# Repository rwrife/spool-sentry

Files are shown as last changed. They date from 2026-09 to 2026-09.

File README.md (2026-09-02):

# Spool Sentry

> USB-powered ESP32-C3 monitor for 3D-printing hobbyists to track dry-box humidity, temperature, and filament spool mass through a private local dashboard without controlling heaters or printers.

## Overview

Spool Sentry is a small, repairable monitor for a passive filament dry box. A load cell under one spool records mass trends while a digital temperature/humidity sensor records the box environment. An ESP32-C3-class controller keeps bounded local history and serves a phone/desktop-friendly web interface on the local network. USB CDC remains the setup and recovery path.

The goal is practical awareness: see whether a box is staying dry, record desiccant changes, and estimate remaining filament after the user enters empty-spool mass. It is **not** a dryer controller, printer integration, certified hygrometer, or safety device.

## Motivation

Opaque boxes hide both environmental drift and dwindling material. Stick-on hygrometers show only the present, and manually weighing a spool interrupts storage. Spool Sentry combines two explainable observations without requiring a vendor account, subscription, or internet service.

## Target users

- Home 3D-printing hobbyists who store moisture-sensitive filament
- Small workshops that want a local history for one frequently used spool
- Makers who prefer editable hardware, replaceable sensors, and portable data

## Concrete use cases

- Check current box humidity and temperature from a phone on the same LAN.
- View hourly trends and annotate a desiccant recharge or spool swap.
- Tare/calibrate the scale, enter an empty-spool mass, and see gross/net mass with an uncertainty indicator.
- Export measurements and events as CSV/JSON before clearing local history.
- Recover configuration over USB if Wi-Fi credentials change.

## Intended workflow

1. Assemble the low-voltage carrier, sensor lead, load-cell platform, and enclosure using the bring-up guide that the backlog will create.
2. Power it from a suitable USB 5 V supply; no battery or mains wiring is part of the project.
3. Hold the physical setup button to open a short-lived onboarding session, then configure local Wi-Fi from the device-hosted page or USB CDC.
4. Calibrate with a documented reference mass, enter the spool's empty mass, and place the spool on the platform.
5. Review live values and local trends, add spool/desiccant events, and export or delete data at any time.

## MVP features

- One replaceable load-cell/ADC channel and one digital humidity/temperature channel
- Explicit sensor freshness, calibration state, and invalid/out-of-range statuses
- Gross mass, user-derived net filament estimate, and visible uncertainty—not false precision
- Bounded flash history with retention controls and event annotations
- Responsive local web UI with keyboard, screen-reader, reduced-motion, high-contrast, and non-color-only states
- Versioned CSV/JSON export and JSON backup/restore
- USB CDC provisioning, diagnostics, firmware recovery, and Wi-Fi-free snapshot access
- Physical setup/tare button and status indicator

## Non-goals

- Heater, fan, mains, battery-charging, relay, or printer control
- Fire, smoke, flood, food, medical, or life-safety monitoring
- Certified environmental measurement or guaranteed filament condition/print quality
- Automatic material-type diagnosis, purchasing, cloud accounts, remote internet access, or multi-site fleet management
- Multi-spool inventory, RFID, camera, or slicing software integration in the MVP

## Privacy, permissions, and data storage

Spool Sentry has no cloud backend, telemetry, advertising, or required account. Measurements, calibration data, annotations, and network configuration remain on the device; exports are created only when requested. The local web app requests no phone contacts, location, camera, microphone, Bluetooth, or notification permission. Wi-Fi access is limited to local setup and local device use. USB works without network access.

The baseline LAN protocol is not a promise of hostile-network security: deployment assumes a trusted home/workshop LAN, uses proof-of-presence onboarding, rejects cross-origin mutation, and keeps remote access disabled. Documentation will explain credential reset, export redaction, retention, deletion, and the limitations of unencrypted local HTTP if that remains the chosen transport.

## Safety limits

- SELV USB 5 V input only; use a suitable enclosed/certified USB supply.
- No connection to printer power, heaters, mains, batteries, or safety interlocks.
- Keep electronics away from hot zones, moving printer parts, liquids, and loose filament paths.
- Load readings are informational. Do not use the platform to support people, hazardous loads, or critical processes.
- Humidity/temperature readings and remaining-filament estimates can drift or fail. The device must surface stale/invalid data rather than imply safety or guaranteed print success.

## Hardware and source-of-truth plan

The planned editable KiCad project is:

- `hardware/spool-sentry.kicad_pro`
- `hardware/spool-sentry.kicad_sch`
- `hardware/spool-sentry.kicad_pcb`

These files **do not exist yet**; this repository is currently a documentation/backlog scaffold. The backlog requires real editable KiCad sources, ERC/DRC evidence, firmware/app builds, bring-up measurements, and fabrication outputs before any hardware-complete claim.

Final BOM data belongs in KiCad schematic symbol properties (`Manufacturer`, `MPN`, supplier fields, and notes) and is exported to tracked `bom/bom.csv`. `bom/preliminary-bom.csv` is planning-only and contains no validated sourcing or prices.

## Current status and milestones

**Status: requirements/architecture baseline plus toolchain proof.** The v0.1 requirements, editable architecture diagrams, protocol schema/fixture, risk register, and verification matrix are frozen. A pinned Rust host-test and ESP32-C3 target-link proof exists, but there is still no schematic, PCB, functional firmware/app, calibrated instrument, fabricated board, assembly, ERC/DRC result, flash/boot evidence, or bench/field test.

1. Freeze measurable requirements and risk boundaries.
2. Select exact components from manufacturer datasheets and create the KiCad schematic/BOM.
3. Lay out and verify the carrier PCB.
4. Build firmware and the local web companion against simulated interfaces.
5. Assemble, calibrate, integrate, and publish honest fabrication/release evidence.

See [PLAN.md](PLAN.md), the canonical [v0.1 requirements](docs/requirements.md), [architecture](docs/architecture.md), [risk register](docs/risk-register.md), [verification matrix](docs/verification-matrix.md), and the GitHub issue backlog.

## Development quickstart

The currently implemented checks require Python 3 plus rustup. The proof pins and installs its exact Rust version, components, and ESP32-C3 target:

```sh
./scripts/verify.sh
```

This checks requirement traceability, local Markdown links, the protocol schema/fixture, Rust formatting/clippy/host tests, and an ESP32-C3 release link. See [the toolchain decision](docs/toolchain.md) for exact evidence limits. KiCad 9+, the companion Node/pnpm workspace, selected-part drivers, flashing, and bench procedures arrive in later issues and must not be presented as working yet.

## License

Initial documentation is available under the MIT License. A mature release will add explicit hardware/firmware/software license files and third-party notices before publishing fabrication outputs.

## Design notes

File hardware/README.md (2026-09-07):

# Hardware design artifacts

This directory now carries the schematic source-of-truth for the Spool Sentry carrier board.

## Included files

- `spool-sentry.kicad_pro` / `spool-sentry.kicad_sch`: KiCad 9 project + schematic
- `sym-lib-table`, `fp-lib-table`: local library bindings used by this schematic
- `lib/spool-sentry.kicad_sym`: project-local custom symbols (XIAO ESP32-C3 module, NAU7802 ADC)
- `lib/spool-sentry.pretty/XIAO_ESP32C3.kicad_mod`: project-local XIAO module footprint
- `lib/spool-sentry.dcm`: symbol documentation metadata

## What this schematic covers

- USB 5V SELV power entry and protection path (USB-C UFP + PPTC + TVS + reverse-current block)
- Controller module (`U1`: Seeed XIAO ESP32-C3)
- Bridge ADC path (`U2`: NAU7802) and load-cell connector (`J2`)
- Environmental sensor path (`U3`: SHT40) on shared I2C
- Dedicated user button (`SW1`) for tare/calibration/recovery interactions
- Status RGB indicator (`D3` + current-limit resistors)
- Test points for safe bring-up/diagnostics

## Regenerating verification artifacts

From the repository root:

```bash
# Schematic ERC (text report)
kicad-cli sch erc --format report \
  --output docs/verification/kicad-erc.rpt \
  hardware/spool-sentry.kicad_sch

# Netlist + BOM exports from schematic symbol properties
./scripts/export_schematic_bom.py hardware/spool-sentry.kicad_sch

# Optional external schematic analyzer outputs (JSON + text)
# (path depends on local Hermes skill checkout)
# python3 <path-to-analyze_schematic.py> hardware/spool-sentry.kicad_sch --output docs/verification/schematic-analysis.json
# python3 <path-to-analyze_schematic.py> hardware/spool-sentry.kicad_sch --output docs/verification/schematic-analysis.txt --text
```

The issue-specific validation summary is in
`docs/verification/issue-2-hardware-schematic.md`.

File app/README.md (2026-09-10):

# Local web companion

Device-hosted accessible companion for Spool Sentry. Built status (issue #5):
implemented and host-tested; not yet exercised on real browsers or a
physical device.

## Responsibilities (implemented)

- connection status and proof-of-presence guidance (onboarding flow text;
  the live onboarding route lands with the firmware LAN adapter in #6)
- live humidity, temperature, gross mass, net estimate, freshness,
  calibration, and fault states from protocol v0.1 snapshot/SSE payloads
- guided tare/reference-mass calibration with confirmation and validation
- spool metadata entry and empty-spool mass (user-entered, never inferred)
- local history view with textual chart summaries and data tables, plus
  desiccant/spool/calibration event annotations
- versioned CSV/JSON export, JSON backup validate → preview → commit,
  retention mirror, scoped deletion, and factory-reset guidance
- diagnostics suitable for redacted support without credentials or stable
  network identifiers

## Layout

- `src/protocol.ts` — v0.1 types, major-version gate, bounded request ids
- `src/state.ts` — link/freshness/history state machine (stale stays visible)
- `src/backup.ts` — backup envelope + FNV-1a parity with firmware
- `src/csvio.ts` — RFC 4180 parser + frozen v0.1 export-header validation
- `src/format.ts` — units, uncertainty text, state/fault sentences
- `src/client.ts` — LAN HTTP/SSE client, same-origin only, injectable
- `src/main.ts` — accessible vanilla-DOM UI rendered into `index.html`
- `fixtures/` — fault/stale/disconnected/saturated/uncalibrated cases
- `scripts/serve_smoke.mjs` — loopback serve + size-budget smoke test

## Commands (from `app/`)

```sh
npm ci
npm run lint    # tsc --noEmit + prettier --check
npm test        # vitest (host; jsdom for structure tests)
npm run build   # tsc --noEmit + vite build -> dist/ (device-hostable)
npm run smoke   # serve dist/ on loopback and check bundle + mock API
```

`./scripts/verify.sh` from the repository root runs all of these in CI.

## Data ownership and permissions

All data remains on the device until the user exports it. No cloud account,
analytics, advertising, third-party API, or internet connection is required.
The app requests no location, contacts, camera, microphone, Bluetooth,
notification, or background-sensor permissions. Browser storage caches
static assets only; authoritative history/configuration stays on the device.
Export, restore, retention, and deletion are explicit user actions. The UI
never fabricates device confirmation tokens; destructive operations guide
the user through on-device presence confirmation.

## Accessibility

Implemented: semantic landmarks, skip link, labelled form controls,
`role=status`/`aria-live` announcements, text-first state descriptions
(never color-only), visible focus styles, `prefers-reduced-motion` and
`prefers-contrast` handling, zoom-friendly layout, and text data tables for
history. Verified by host tests (`test/ui.test.ts`) inside jsdom only.
Manual screen-reader, 200% zoom, and real-browser checks (Android Chrome,
iOS Safari, Windows Edge, macOS Safari) are **not yet performed** and stay
tracked in the verification matrix (UX-001) for issue #6.

## Protocol boundary

`docs/protocol.md` is the versioned boundary and its
"Implementation reconciliation" section records the exact payload shapes
this app implements and contract-tests. The app tolerates additive minor
fields, rejects unsupported majors before touching stored data, validates
imports before mutation, and shows offline/stale states instead of silently
reusing old readings.

## Test strategy (status)

- unit tests for formatting/uncertainty/state machine/import validation —
  done (host)
- contract tests against the canonical schema and firmware-shaped backup
  envelopes — done (host)
- structure/label/live-region component tests — done in jsdom only
- production build, asset-size budget, loopback device-host serve test —
  done (Linux/node)
- browser smoke tests on real Android/iOS/Windows/macOS browsers — not
  performed; required before any compatibility claim (issue #6)

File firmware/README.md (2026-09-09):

# Firmware plan and toolchain baseline

The frozen firmware requirements are [FW-001 and FW-002](../docs/requirements.md), and the transport/data contract is [`docs/protocol.md`](../docs/protocol.md).

## Primary toolchain

Issue #1 proved a pinned stable Rust/ESP32-C3 path in [`toolchain-proof`](toolchain-proof):

```sh
./scripts/verify.sh
```

That command runs documentation/schema checks, formatting, host clippy/tests, target clippy, and an ESP32-C3 release link. See [`docs/toolchain.md`](../docs/toolchain.md) for exact versions, evidence limits, and the bounded ESP-IDF fallback gate.

## Responsibilities

- Initialize and supervise environmental sensor, load-cell ADC, button/status, storage, USB, and Wi-Fi adapters.
- Sample at bounded rates; separate raw diagnostics from filtered/stable observations.
- Track freshness, settling, saturation, disconnect, calibration, and storage faults explicitly.
- Compute gross and user-derived net mass with honest precision and uncertainty metadata.
- Maintain bounded versioned configuration/history with migration and interrupted-write recovery.
- Serve the companion bundle and versioned local HTTP/SSE API; support the required USB CDC offline subset.

Domain logic stays in host-testable `no_std` code behind sensor, monotonic/wall clock, storage, USB, and network interfaces. That domain core now exists in [`domain`](domain) with host tests, target build, and pinned flash/erase/recovery commands; exact hardware driver integration waits for issue #6 bring-up against the issue #2 parts.

## Evidence boundary

The domain crate host-tests domain behavior against simulated hardware and links a release image for ESP32-C3 with a size report, but nothing has been flashed or run on a board. Issue #6 owns driver integration, serial/bench evidence, and calibration. See [`domain/README.md`](domain/README.md) for exact commands and evidence limits.

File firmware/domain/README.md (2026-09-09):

# Firmware domain core (`spool-sentry-domain`)

Host-testable, allocation-free (`no_std`) domain logic for the ESP32-C3
spool-sentry device (issue #4). All hardware interaction happens through
injected adapter traits, so every behavior below is exercised on the host
with fakes before any board exists.

## What lives here

| Module | Responsibility |
|---|---|
| `json` | Bounded parser/writer for the frozen command grammar (size/depth caps, strict number grammar, no exponent/NaN input) |
| `rpc` | Transport-neutral command router shared by LAN HTTP and USB CDC; identical semantics on both (PROTO-003); request rate budget |
| `faults` | Stable machine-readable fault codes matching `^[a-z0-9_]+$`; disconnect/saturation/out-of-range never merged |
| `fresh` | Freshness/staleness thresholds and classification |
| `sensors` | Reading envelopes (`Ok`/`Disconnected`/`Saturated`/`OutOfRange`/`ImpossibleValue`) and adapter traits |
| `filter` | Median-of-window mass filter with stability detection; resets on disconnect |
| `mass` | Gross/net arithmetic, user-entered empty-spool mass, negative-net fault |
| `calibration` | Two-point tare/reference lifecycle with single-use random tokens, expiry, and invalidation |
| `observation` | Deterministic observation JSON conforming to `docs/schemas/observation-v0.1.schema.json` |
| `csv` | CSV export rows with explicit units, time basis, quality, age, calibration state, uncertainty, faults |
| `store` | Dual-slot objects with FNV-1a checksums, interrupted-write recovery (staging/primary), capacity-exceeded behavior, retention-bounded event log, deletion scopes |
| `backup` | Validate → preview → commit backup envelope; credentials are structurally excluded |
| `presence` | Physical-presence sessions: button opens a nonce session; mutations require a recent session; expiry is automatic |
| `timefmt` | RFC 3339 UTC formatting/parsing without `alloc`; wall-clock changes never mutate stored history |
| `core` | `DeviceCore::observe` sampling pipeline tying it all together |

## Reproduce

From the repository root: `./scripts/verify.sh` runs both crates. To work
on this crate alone (rustup discovers the pin in this directory):

```sh
cd firmware/domain
cargo fmt --all -- --check
HOST="$(rustc -vV | sed -n 's/^host: //p')"
cargo clippy --lib --tests --target "$HOST" --locked -- -D warnings
cargo test --target "$HOST" --locked          # host: 74 unit + 3 fixture-contract tests
cargo clippy --release --locked -- -D warnings # ESP32-C3 no_std clippy
cargo build --release --locked                 # links the ESP32-C3 image
size -A target/riscv32imc-unknown-none-elf/release/spool-sentry-domain
```

The host test profile (`cfg(test)`) may use `std`/`alloc`; the firmware
profile is `no_std`, allocation-free, and depends only on `heapless`.
`tests/observation_fixtures.rs` validates the emitted bytes against the
real repository schema and fixture files, so firmware and companion-app
data cannot drift apart.

## Flashing, serial, erase/recovery (pinned tools)

Pinned host tool: `espflash 4.5.0` (installed with
`cargo install espflash --locked --version 4.5.0`). `.cargo/config.toml`
wires the runner so `cargo run --release` flashes and monitors. The exact
USB topology (native USB-Serial-JTAG vs. UART bridge) is finalized in
issue #6 bring-up; commands below are the selected toolchain's documented
interfaces.

```sh
# Flash the release image and open the serial monitor
cargo run --release                       # = espflash flash --monitor --chip esp32c3 <image>
espflash flash --monitor --chip esp32c3 \
  target/riscv32imc-unknown-none-elf/release/spool-sentry-domain

# Serial log (monitor without flashing)
espflash monitor --chip esp32c3

# Factory reset: erase all device data (configuration, history, calibration)
espflash erase-flash --chip esp32c3

# USB recovery: hold BOOT (IO9) while resetting to enter the ROM bootloader,
# then re-flash over USB; espflash auto-detects the bootloader:
espflash flash --chip esp32c3 target/riscv32imc-unknown-none-elf/release/spool-sentry-domain
```

The current bin (`src/bin/main.rs`) is a tool/link-path proof for the
domain core on the real target; driver integration (NAU7802 ADC, SHT40,
flash, USB CDC, Wi-Fi/HTTP server) lands with issue #6 bring-up.

## Evidence boundary (honesty rule)

- Host tests prove domain behavior against simulated hardware only.
- The release build proves the domain links for `riscv32imc-unknown-none-elf`;
  the linked ELF size is reported by CI.
- Nothing here has been flashed, booted, measured, or bench-tested. No
  on-device timing, accuracy, connectivity, or battery claims are made.
- Uncertainty is reported as `null` with the `uncertainty_not_characterized`
  fault until issue #6 produces calibrated bench evidence.

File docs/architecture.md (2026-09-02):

# Spool Sentry v0.1 architecture

This architecture implements the frozen boundary in [requirements.md](requirements.md). Diagrams are Mermaid/text source and remain editable in git.

## End-to-end blocks

```mermaid
flowchart LR
  USB[USB 5 V SELV] --> PROTECT[Input protection]
  PROTECT --> RAIL[3.3 V rail]
  RAIL --> MCU[ESP32-C3 module]
  RAIL --> ENV[Temperature/RH sensor]
  RAIL --> ADC[Load-cell ADC]
  CELL[Replaceable bar load cell] --> ADC
  ENV --> MCU
  ADC --> MCU
  BUTTON[Setup/tare button] --> MCU
  MCU --> STATUS[Text-documented status indicator]
  MCU --> FLASH[Bounded config/history]
  MCU --> CDC[USB CDC setup/recovery/export]
  MCU --> HTTP[Local HTTP JSON + SSE]
  HTTP --> WEB[Device-hosted accessible web app]
```

Only observation data crosses the sensor boundary. There is no actuator output.

## Power domains

```mermaid
flowchart TD
  SUPPLY[Suitable enclosed USB supply] --> CABLE[Data-capable USB cable]
  CABLE --> VBUS[Protected USB VBUS test point]
  VBUS --> REG[3.3 V regulator]
  REG --> V33[3V3 test point]
  V33 --> RADIO[ESP32-C3]
  V33 --> DIGITAL[Environmental sensor]
  V33 --> ANALOG[Load-cell ADC/bridge excitation]
  VBUS --> GND[Common SELV ground/test point]
  V33 --> GND
```

Issue #2 must replace generic blocks with datasheet-backed parts and document worst-case/inrush current with 20% path margin. The PCB shall keep load-cell analog routing/return away from radio and digital switching.

## Data and ownership

```mermaid
flowchart LR
  SENSOR[Sensor samples] --> VALIDATE[Range/status validation]
  VALIDATE --> FILTER[Bounded filters + stability]
  FILTER --> OBS[Versioned observation]
  OBS --> LIVE[LAN SSE / USB snapshot]
  OBS --> AGG[Hourly aggregate]
  AGG --> STORE[Bounded local history]
  EVENT[User events/metadata] --> STORE
  STORE --> EXPORT[User-triggered CSV/JSON export]
  STORE --> BACKUP[Versioned backup]
  BACKUP --> CHECK[Validate + preview]
  CHECK -->|explicit commit| STORE
  DELETE[Confirmed scoped deletion] --> STORE
```

The device is authoritative. The browser may cache static assets and ephemeral preferences, not authoritative history or credentials. Restore never mutates before validation and explicit commit.

## Provisioning and recovery

```mermaid
sequenceDiagram
  actor User
  participant Button as Physical button
  participant Device
  participant Client as LAN client or USB host
  User->>Button: Hold to request presence session
  Button->>Device: Local hardware event
  Device-->>Client: Short-lived random session capability
  Client->>Device: Provision/configure with bounded request
  Device-->>Client: Result without echoing credentials
  Device->>Device: Expire session automatically
  alt Wi-Fi unavailable or invalid
    User->>Device: Connect USB CDC
    Client->>Device: status/snapshot/diagnostics/export
    User->>Button: Confirm destructive recovery if needed
    Client->>Device: provision/delete/reset
  end
```

LAN HTTP assumes a trusted network and is not exposed through a cloud relay, port mapping, or internet discovery. USB is the mandatory offline recovery path.

## Mechanical force path

```mermaid
flowchart TD
  SPOOL[One spool: centered working load ≤ 2.5 kg] --> TOP[Removable platform]
  TOP --> MOUNT_A[Specified load-introduction fasteners]
  MOUNT_A --> CELL[Replaceable ≥5 kg bar load cell]
  CELL --> MOUNT_B[Fixed-end fasteners + spacers]
  MOUNT_B --> BASE[Rigid base/enclosure]
  BASE --> FEET[Stable support surface]
  PCB[Electronics carrier] -. mechanically isolated .-> BASE
  ENV[Ventilated environmental sensor] -. away from MCU/regulator .-> BASE
```

The moving platform may not contact the PCB or enclosure over the working range. Off-center and overload behavior remain bench-verification items; the design shall not claim universal spool fit.

## Responsibility boundaries

| Boundary | Owns | Does not own |
|---|---|---|
| Hardware | protected SELV input, sensors, controller, test/debug access, carrier, force path | mains/battery/charging, actuation, safety interlocks |
| Firmware | sampling, quality/fault state, calibration, bounded storage, protocol, provisioning/recovery | cloud service, print prediction, certified measurement |
| Companion | accessible local workflows, history, events, export/restore/deletion | authoritative storage, phone permissions, cloud sync |
| Protocol | versioned bounded LAN/USB semantics and fixtures | hostile-internet security, remote access |

## Dependency gates

1. This requirements/architecture baseline gates exact part selection (#2), host-domain firmware (#4), and fixture-first companion work (#5).
2. Exact hardware drivers wait for the datasheet-backed pins and interfaces from #2.
3. PCB/mechanics (#3) wait for the reviewed schematic and exact parts.
4. Bench claims and release outputs wait for an assembled prototype (#6/#7).

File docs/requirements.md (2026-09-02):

# Spool Sentry v0.1 requirements

**Status:** frozen planning baseline for v0.1. Values below are design targets until the verification matrix records matching evidence. This document is the canonical requirement set; subsystem documents link back to these stable IDs.

## Product boundary

| ID | Requirement |
|---|---|
| PRD-001 | The MVP observes exactly one removable spool using one load-cell channel and one dry-box environmental channel. Multi-spool inventory is out of scope. |
| PRD-002 | The device is observation-only and shall expose no heater, fan, relay, printer-power, printer-control, battery, or charger interface. |
| PRD-003 | Core use shall be local/offline-first with no account, cloud backend, telemetry, advertising, or required internet service. |

## Power and electrical behavior

| ID | Requirement |
|---|---|
| PWR-001 | Accept nominal USB 5 V SELV input only from a suitable enclosed supply; exact connector protection and acceptable input tolerance require datasheet verification in issue #2. |
| PWR-002 | The exact-parts design shall document worst-case load and inrush and retain at least 20% continuous-current margin in the supply, protection, regulator, connector, and PCB path. |
| PWR-003 | Power-up, sensor disconnect, ADC saturation, invalid calibration, and storage faults shall become explicit states; no missing or failed input may be represented as a valid zero. |

## Measurement semantics and targets

| ID | Requirement |
|---|---|
| MEAS-001 | Report temperature and relative humidity with sample age, status, and the selected sensor's documented accuracy limits over the product target of 10–35 °C and 10–80% RH, non-condensing. |
| MEAS-002 | Support a centered 0–2.5 kg gross platform/spool operating range; select a load cell with rated capacity at least 5 kg and verify the complete mechanical overload path. |
| MEAS-003 | After warm-up and valid calibration, target repeatability within the greater of 5 g or 1% of applied mass for centered references from 100 g through 2.0 kg. This is a bench target, not a current claim. |
| MEAS-004 | Display resolution shall not imply more precision than calibration and repeatability evidence supports; raw ADC counts remain diagnostic data. |
| MEAS-005 | Net filament estimate equals stable gross mass minus the user-entered empty-spool mass. It shall include units, calibration state, freshness, and uncertainty; negative results remain visible as invalid/configuration faults rather than being silently clamped. |
| MEAS-006 | Calibration records shall include schema version, timestamp or explicit unknown-time state, reference mass, scale factor, zero offset, uncertainty metadata, and invalidation reason. Relevant sensor/configuration changes invalidate calibration. |

Terminology is normative:

- **Accuracy** is closeness to a traceable reference and is not claimed before bench comparison.
- **Repeatability** is agreement among repeated readings under stated conditions and uses MEAS-003.
- **Display resolution** is the smallest shown increment; it is not accuracy.
- **Uncertainty** is the stated interval/estimate derived from sensor, calibration, repeatability, drift, and quantization evidence. Until measured, the UI says **uncertainty not characterized**.

## Mechanical and environmental boundary

| ID | Requirement |
|---|---|
| MECH-001 | The platform shall support a centered 2.5 kg static working load without the moving load path touching the PCB; overload and off-center limits require bench evidence before publication. |
| MECH-002 | Load cell, environmental sensor, USB cable, and electronics carrier shall be replaceable with ordinary hand tools, with strain relief and unambiguous orientation. |
| MECH-003 | Place the vented environmental sensor away from MCU/regulator heat and filament contact; document distance, airflow assumptions, and bring-up comparison. |
| MECH-004 | Release editable mechanical source for the force path and common-spool fit envelope without claiming universal spool compatibility. |

## Data ownership, retention, and recovery

| ID | Requirement |
|---|---|
| DATA-001 | Store at least 30 complete days of hourly aggregates. The v0.1 default target is a rolling 90 days; final capacity and flash wear shall be measured before release. High-rate raw samples are not retained by default. |
| DATA-002 | User-triggered exports shall provide versioned CSV and JSON with explicit units, quality/fault fields, time-basis metadata, and no credentials or stable hardware/network identifiers. |
| DATA-003 | Backups shall be versioned and integrity checked. Restore is a validate → preview → explicit commit transaction; validation failure or interrupted commit preserves the prior committed state. |
| DATA-004 | Users shall be able to delete history, spool metadata, calibration, network credentials, or all user data by explicit scope. Destructive operations require fresh confirmation and report completion/failure. |
| DATA-005 | Configuration/history storage shall be bounded and versioned, detect corruption, recover from interrupted writes, expose storage-full behavior, and apply retention without silently discarding the newest unexported data. |

## Connectivity, privacy, and protocol

| ID | Requirement |
|---|---|
| CONN-001 | The v0.1 LAN transport is local HTTP/1.1 JSON plus one-way Server-Sent Events (SSE) for live observations. WebSocket and remote-internet access are not part of v0.1. |
| CONN-002 | Wi-Fi onboarding and sensitive mutation require a recent, short-lived physical-presence session initiated by the setup button and expiring automatically. |
| CONN-003 | Without Wi-Fi or internet, USB CDC shall provide version/capability status, current snapshot, diagnostics, provisioning/recovery, user-data export/backup, and confirmed scoped deletion/factory reset. The web UI itself need not be served over USB. |
| CONN-004 | The product shall not implement telemetry, cloud relay, automatic port mapping, internet discovery, remote administration, or baseline phone sensor permissions. |
| SEC-001 | Documentation shall disclose that unencrypted local HTTP assumes a trusted LAN. Implementations shall reject unexpected Host/Origin values and enforce bounded body sizes, parser depth, rates, and timeouts. |
| SEC-002 | Wi-Fi credentials are write-only after provisioning and shall not appear in normal logs, diagnostics, backups, exports, or support bundles. Device IDs are random and resettable rather than raw chip identifiers. |
| PROTO-001 | Protocol version `0.1` uses major-version rejection and additive-minor compatibility. Every response carries `protocol_version`; request/response operations carry bounded `request_id` values. |
| PROTO-002 | Observation payloads shall conform to `docs/schemas/observation-v0.1.schema.json`; value availability, freshness, calibration, uncertainty, and faults are explicit and non-color-only. |
| PROTO-003 | LAN and USB operations share semantic fixtures and error codes. Invalid, oversized, unsupported, or malformed input fails closed without mutation or loss of current committed data. |

## Firmware, UI, evidence, and source

| ID | Requirement |
|---|---|
| FW-001 | The primary firmware toolchain is pinned stable Rust targeting ESP32-C3 with `esp-hal`; a host-testable `no_std` domain core is separated from hardware adapters. `firmware/toolchain-proof` is the build proof. |
| FW-002 | Filters, calibration, retention, migration, protocol, and fault-state logic shall run in host tests through injected sensor, clock, storage, USB, and network boundaries. |
| UX-001 | Primary web flows shall support keyboard use, screen-reader semantics, visible focus, 200% text scaling, reduced motion, high contrast, and textual chart summaries/data tables. |
| UX-002 | Fresh, stale, invalid, uncalibrated, saturated, disconnected, and storage-fault states shall use text/icon semantics in addition to color and shall never reuse stale values without age/status. |
| SAFE-001 | Intended use is indoor hobby/workshop observation in a passive, non-condensing dry box within the target range in MEAS-001. |
| SAFE-002 | Documentation shall prohibit heated dryers/ovens, printer enclosures/power/control, mains, batteries/charging, wet locations, people/hazardous loads, and safety-critical use. |
| SAFE-003 | The product shall not claim certified metrology, certified humidity, filament condition/dryness, fire prevention, print success, or safety-alarm behavior. |
| REL-001 | Reports and UI documentation shall distinguish static analysis, simulation, host tests, target build, bench measurement, and field testing. Unperformed evidence stays explicit. |
| COST-001 | Target one-prototype cost is USD 35–60 with a USD 75 ceiling, excluding tools, shipping, tax, phone/computer/printer, and calibration reference; only dated live evidence may populate prices. |
| SRC-001 | Release editable KiCad/mechanical/firmware/app sources. Exact Manufacturer/MPN/supplier/BOM comments live in KiCad symbol properties and export to tracked `bom/bom.csv`; planning placeholders are not sourced parts. |

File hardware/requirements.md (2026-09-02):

# Hardware requirement subset

The canonical frozen requirements are in [`docs/requirements.md`](../docs/requirements.md). Hardware design work shall trace to these IDs rather than creating alternate values.

## Applicable IDs

- Product boundary: PRD-001 through PRD-003
- Power/electrical: PWR-001 through PWR-003
- Measurement: MEAS-001 through MEAS-006
- Mechanical/environment: MECH-001 through MECH-004 and SAFE-001 through SAFE-003
- Connectivity/test access constraints: CONN-003, SEC-002
- Cost/source: COST-001, SRC-001

## Frozen design inputs

- One load-cell channel and one environmental channel.
- Centered gross operating range: 0–2.5 kg.
- Load-cell rated capacity: at least 5 kg, with the complete force path still requiring mechanical verification.
- Product environment target: 10–35 °C and 10–80% RH, non-condensing, passive dry box only.
- USB 5 V SELV only; no battery, charger, mains, heater, fan, relay, printer power/control, or safety output.
- Exact parts, input tolerance, current budget, sensor performance, packages, pinouts, and footprints remain issue #2 datasheet decisions and must not be invented here.

See [`docs/architecture.md`](../docs/architecture.md) for power and force-path diagrams, [`docs/risk-register.md`](../docs/risk-register.md) for controls, and [`docs/verification-matrix.md`](../docs/verification-matrix.md) for required evidence.

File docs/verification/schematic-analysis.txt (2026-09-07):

=== Design Analysis ===

--- analog ---
  [1] INFO AD-DET: ADC U2 (NAU7802SGI) 24-bit
      Detail: Detected external ADC U2 (24-bit).
      Component: U2
      Stages: schematic

--- certification ---
  [2] INFO CERT-001: Wireless module detected: U1
      Detail: FCC Part 15: Wireless module detected: U1
      Stages: schematic

--- component_derating ---
  [3] INFO VD-004: C2 (100nF 50V X7R) is over-designed for +5V_XIAO (50V on 5.0V rail)
      Detail: 50V-rated capacitor on a 5.0V rail — margin 90.0%.
      Fix:    Consider 16V rating — 50V is significantly over-designed for a 5.0V rail
      Stages: schematic
  [4] INFO VD-004: C4 (100nF 50V X7R) is over-designed for +3V3 (50V on 3.3V rail)
      Detail: 50V-rated capacitor on a 3.3V rail — margin 93.4%.
      Fix:    Consider 10V rating — 50V is significantly over-designed for a 3.3V rail
      Stages: schematic
  [5] INFO VD-004: C6 (1uF 16V X7R) is over-designed for AVDD_3V0 (16V on 3.0V rail)
      Detail: 16V-rated capacitor on a 3.0V rail — margin 81.2%.
      Fix:    Consider 10V rating — 16V is significantly over-designed for a 3.0V rail
      Stages: schematic

--- component_integrity ---
  [6] ERROR LR-001: LED D3: no current-limiting resistor found
      Detail: LED D3 (RGB STATUS) has no series current-limiting resistor.
      Fix:    Add a current-limiting resistor (typically 330R-1k for 3.3V).
      Stages: schematic

--- debug ---
  [7] INFO DI-DET: Debug interface J3 (debug): pass
      Detail: Detected debug debug interface on connector J3.
      Stages: schematic, bring_up

--- decoupling ---
  [8] INFO DC-DET: Decoupling on +5V_XIAO
      Detail: Decoupling capacitors on power rail +5V_XIAO
      Stages: schematic, layout
  [9] INFO DC-DET: Decoupling on VBUS
      Detail: Decoupling capacitors on power rail VBUS
      Stages: schematic, layout
  [10] INFO DC-DET: Decoupling on +3V3
      Detail: Decoupling capacitors on power rail +3V3
      Stages: schematic, layout
  [11] INFO DC-DET: Decoupling on AVDD_3V0
      Detail: Decoupling capacitors on power rail AVDD_3V0
      Stages: schematic, layout

--- decoupling_coverage ---
  [12] INFO DO-DET: Decoupling coverage on +5V_XIAO
      Detail: Decoupling frequency coverage for rail +5V_XIAO
      Stages: schematic
  [13] INFO DO-DET: Decoupling coverage on VBUS
      Detail: Decoupling frequency coverage for rail VBUS
      Stages: schematic
  [14] INFO DO-DET: Decoupling coverage on +3V3
      Detail: Decoupling frequency coverage for rail +3V3
      Stages: schematic
  [15] INFO DO-DET: Decoupling coverage on AVDD_3V0
      Detail: Decoupling frequency coverage for rail AVDD_3V0
      Stages: schematic

--- i2c_bus ---
  [16] INFO DO-DET: I2C SCL bus on I2C_SCL
      Detail: I2C SCL bus detected with 2 device(s)
      Stages: schematic
  [17] INFO DO-DET: I2C SDA bus on I2C_SDA
      Detail: I2C SDA bus detected with 2 device(s)
      Stages: schematic

--- lifecycle ---
  [18] INFO LC-007: Lifecycle audit not run — --lifecycle flag not passed
      Detail: Component lifecycle / obsolescence audit was not run this session. Reason: --lifecycle flag not passed (run with --lifecycle to query DigiKey / Mouser / LCSC / element14 for obsolescence + operating-temp coverage; requires network + API keys). The review cannot report active / NRND / EOL / obsolete status, last-time-buy windows, or operating-temperature coverage for any BOM part. Treat the lifecycle section of the report as 'not performed'.
      Fix:    Run with --lifecycle (requires DIGIKEY_CLIENT_ID / MOUSER_SEARCH_API_KEY / ELEMENT14_API_KEY env vars; LCSC needs no auth) to populate this section. If intentionally skipped, note it explicitly in the report's 'Not Performed' section.
      Stages: schematic

--- passive_filters ---
  [19] INFO RC-DET: RC filter R7/C10 at 159.15Hz
      Detail: low-pass RC filter
      Stages: schematic
  [20] INFO RC-DET: RC filter R3/C8 at 33862.75Hz
      Detail: RC-network RC filter
      Stages: schematic
  [21] INFO RC-DET: RC filter R4/C8 at 33862.75Hz
      Detail: RC-network RC filter
      Stages: schematic

--- protection ---
  [22] INFO EP-AUD: ESD audit J1 (usb): none coverage
      Detail: ESD protection audit for usb connector J1: none coverage.
      Stages: schematic
  [23] INFO EP-AUD: ESD audit J2 (header): none coverage
      Detail: ESD protection audit for header connector J2: none coverage.
      Stages: schematic
  [24] INFO EP-AUD: ESD audit J3 (uart): none coverage
      Detail: ESD protection audit for uart connector J3: none coverage.
      Stages: schematic
  [25] INFO EP-AUD: ESD audit U3 (header): none coverage
      Detail: ESD protection audit for header connector U3: none coverage.
      Stages: schematic
  [26] INFO PD-DET: Protection D1 diode
      Detail: Protection device (diode) on VBUS
      Component: D1
      Stages: schematic
  [27] INFO PD-DET: Protection D2 reverse_polarity
      Detail: Protection device (reverse_polarity) on +5V_XIAO
      Component: D2
      Stages: schematic
  [28] INFO PD-DET: Protection F1 fuse
      Detail: Fuse/polyfuse protection on VBUS_FUSED
      Component: F1
      Stages: schematic

--- signal_integrity ---
  [29] WARNING PU-001: U2 pin DRDY (__unnamed_14) missing pull-up resistor
      Detail: Pin DRDY on U2 (NAU7802SGI) is connected to net __unnamed_14 but has no pull-up resistor. This pin type typically requires an external pull-up to a power rail for correct operation.
      Fix:    Add a 4.7k-10k pull-up resistor from __unnamed_14 to the appropriate power rail.
      Stages: schematic
  [30] ERROR VM-001: Net I2C_SCL: 5.0V / 3.3V domain crossing without level shifter
      Detail: Net I2C_SCL connects ICs in 5.0V and 3.3V domains. The 5.0V output may exceed the 3.3V input absolute maximum rating of 3.6V, risking damage.
      Fix:    Add a level shifter between the 5.0V and 3.3V domains on net I2C_SCL, or verify that the connected ICs have tolerant inputs.
      Stages: schematic
  [31] ERROR VM-001: Net I2C_SDA: 5.0V / 3.3V domain crossing without level shifter
      Detail: Net I2C_SDA connects ICs in 5.0V and 3.3V domains. The 5.0V output may exceed the 3.3V input absolute maximum rating of 3.6V, risking damage.
      Fix:    Add a level shifter between the 5.0V and 3.3V domains on net I2C_SDA, or verify that the connected ICs have tolerant inputs.
      Stages: schematic

--- verification ---
  [32] WARNING DS-002: No datasheets directory found (32/32 parts have MPNs). Sync datasheets before making pin-level claims.
      Fix:    Run datasheet sync via the digikey / mouser / lcsc / element14 skill (which one depends on the user's distributor access and API credentials). A ./datasheets/ directory with PDFs and a manifest.json enables pin-level verification in the next analyzer run.
      Stages: schematic

--- wireless ---
  [33] INFO WL-001: wifi/ble module U1 (Seeed XIAO ESP32-C3)
      Detail: Detected wifi_ble wireless module U1 (Seeed XIAO ESP32-C3).
      Stages: schematic, bring_up

Total: 33 (3 errors, 2 warnings, 28 info)

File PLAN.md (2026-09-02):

# Spool Sentry implementation plan

## Frozen scope

Build a one-spool, observation-only passive dry-box monitor with editable low-voltage hardware, embedded firmware, and a device-hosted accessible companion. It measures environment and platform mass, stores bounded local history, supports explicit calibration/spool metadata, and provides user-owned export/backup/deletion. It never actuates a dryer or printer.

The authoritative v0.1 planning set is:

- [frozen requirements](docs/requirements.md)
- [editable architecture diagrams](docs/architecture.md)
- [protocol v0.1](docs/protocol.md)
- [risk register](docs/risk-register.md)
- [verification matrix](docs/verification-matrix.md)
- [firmware toolchain decision](docs/toolchain.md)

## Milestones and dependencies

1. **M1 — requirements/architecture:** freeze measurable ranges, semantics, retention, offline behavior, protocol, risk controls, and toolchain proof. No dependency.
2. **M2 — datasheet-backed parts/schematic:** exact manufacturer parts, KiCad properties, pin/package/footprint checks, ERC, and exported `bom/bom.csv`. Depends on M1.
3. **M3 — PCB/mechanics:** antenna/analog/thermal-aware layout, force path, DRC/cross-domain analysis, and review-only fabrication preview. Depends on M2.
4. **M4 — firmware:** host-tested domain logic, selected-part adapters, local HTTP/SSE and USB CDC, storage, target build/flash/recovery. Depends on M1; hardware integration depends on M2.
5. **M5 — companion:** fixture-first accessible local UI, calibration/history/events, export/restore/deletion. Depends on M1 and coordinates with M4 fixtures.
6. **M6 — integration:** assembled bring-up, calibration/repeatability/fault evidence, documentation, and limitations. Depends on M2–M5.
7. **M7 — release:** inspected fabrication/source/BOM/binaries/licenses/archive from a tagged revision. Depends on M6.

## Verification policy

Static analysis, simulation, host tests, target builds, bench measurements, and field observations are separate evidence classes. A clean target build does not mean firmware booted; an unbuilt board is not tested; one bench prototype does not establish field durability. Every requirement remains planned until the [verification matrix](docs/verification-matrix.md) links adequate evidence.

From the repository root, run the currently available checks with:

```sh
./scripts/verify.sh
```

Future milestones must extend that command/CI rather than replacing evidence with prose.

## Packaging direction

A release eventually includes editable KiCad/mechanical source, schematic PDF, inspected Gerbers/drills/BOM/CPL, pinned firmware source/binaries/checksums, compressed companion assets, assembly/bring-up/recovery docs, and hardware/firmware/software/third-party notices. No app store, cloud account, telemetry, or internet service is required.

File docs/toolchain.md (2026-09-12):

# Firmware toolchain decision and proof

## Decision

The v0.1 primary firmware path is bare-metal stable Rust for ESP32-C3:

- Rust `1.98.0` pinned by `firmware/toolchain-proof/rust-toolchain.toml`
- target `riscv32imc-unknown-none-elf`
- `esp-hal` `1.1.2` with its `esp32c3` feature
- `esp-bootloader-esp-idf` `0.5.0`
- edition 2024 and committed `Cargo.lock`

This target is supported by upstream stable Rust; no custom Xtensa compiler is required for ESP32-C3. The proof initializes the ESP32-C3 HAL and links an ESP-IDF-compatible image. Its `no_std` library exercises the planned host-test boundary with quality-state logic.

This is **target-build evidence only**. No board was connected, flashed, booted, or measured.

## Reproduce

From the repository root:

```sh
./scripts/verify.sh
```

Or run the stages directly (the working directory is significant because rustup discovers the pin there):

```sh
python3 scripts/check_docs.py
cd firmware/toolchain-proof
cargo fmt --all -- --check
HOST="$(rustc -vV | sed -n 's/^host: //p')"
cargo clippy --lib --target "$HOST" --locked -- -D warnings
cargo test --lib --target "$HOST" --locked
cargo clippy --release --locked -- -D warnings
cargo build --release --locked
```

Issue #4 added the host-testable domain crate at `firmware/domain`
(see its [README](../firmware/domain/README.md) for module map, exact
test/build/flash/erase/recovery commands, and evidence limits). The
pinned tool automatically installs `rust-src` and the ESP32-C3 target
through rustup.

Flashing is pinned to `espflash 4.5.0`
(`cargo install espflash --locked --version 4.5.0`), wired as the cargo
runner in each crate's `.cargo/config.toml`. The exact USB topology
(native USB-Serial-JTAG vs. UART bridge) is finalized in issue #6
bring-up; no board has been flashed in this repository to date.

## Architecture rule

Domain logic shall remain in a host-testable `no_std` library. Hardware-specific sensor, clock, storage, USB, and network adapters may depend on ESP crates. Protocol fixtures are shared with the companion app; neither target adapters nor a fallback may redefine protocol semantics.

## Companion toolchain (issue #5)

- Node.js `22.23.1` / npm `10.9.8` pinned in CI via `actions/setup-node` (SHA-pinned v5); local development may use any Node 22.x, but CI is authoritative.
- `app/package.json` + committed `app/package-lock.json` pin every dev dependency (TypeScript 5.6.3, Vite 5.4.11, Vitest 2.1.8, Ajv 8.17.1 + ajv-formats 3.0.1 for schema contract tests, jsdom 25.0.1, Prettier 3.3.3).
- Build is `tsc --noEmit` followed by `vite build`; tests run under Vitest on Node.
- `./scripts/verify.sh` runs the companion gates (lint, tests, build, loopback serve smoke) after the firmware stages and skips them with an explicit message when npm is missing.
- The bundle is dependency-free vanilla TypeScript so the device can host `app/dist/` verbatim; the smoke script enforces a raw size budget (<50 kB JS, <10 kB CSS).

Smoke evidence to date is Linux/node + jsdom only. The browser-matrix claims (Android Chrome, iOS Safari, Windows Edge, macOS Safari) remain not-performed until real devices are exercised in issue #6.

## Bounded fallback gate

Rust remains the default unless issue #4 records a reproducible blocker in the exact selected module path after a time-boxed integration attempt. A fallback may be invoked only if one of these blocks the required target/CI evidence:

1. selected-module Wi-Fi/USB support cannot build on the pinned stable toolchain;
2. a required maintained driver cannot satisfy the selected part's documented interface;
3. a toolchain defect prevents a clean target image and has no bounded patch/upstream release.

If triggered, use a pinned Espressif ESP-IDF C/C++ toolchain only for target adapters and orchestration. Preserve the versioned protocol schemas/fixtures, fault semantics, storage/export behavior, and equivalent host tests. Record the blocker, versions, minimal reproducer, decision date, and migration cost in an architecture decision record before changing implementation language. The fallback does not authorize cloud, actuation, weaker validation, or unsupported hardware claims.

## Hardware verification toolchain (issue #3)

- `kicad-cli` on this machine is a Docker wrapper for the pinned image
  `parts-tally-kicad:9-arm64` (KiCad 9.0.9); all pcbnew-API scripts run in
  that image via `docker run --user $(id -u):$(id -g)` (see
  `scripts/*.py` usage strings).
- Autorouter: FreeRouter `2.1.0` headless with Temurin JDK 21
  (class-file 65; the JDK 17 copy fails `UnsupportedClassVersionError`).
  Incremental passes use `-hf true` (fanout mode converges to natural exit
  and writes the SES session; full-mode plateau never flushes).
- Mechanics: OpenSCAD `2021.01` via Docker image
  `parts-tally-openscad:arm64` (`scripts/export_mechanical_stl.sh`);
  STL outputs are review-only previews, not fabricated parts.
- BOM tooling unchanged (issue #2); no new schematic inputs were added in
  issue #3, so `bom/bom.csv` is re-exported from the same properties.

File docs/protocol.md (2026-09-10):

# Device/companion protocol v0.1

**Status:** frozen design contract; schema/fixture validation exists, but no firmware/app interoperability or physical-device evidence exists yet. Requirements: [PROTO-001 through PROTO-003](requirements.md).

## Transport decision

- **LAN:** HTTP/1.1 JSON request/response plus Server-Sent Events (SSE) for one-way live observations.
- **USB:** CDC newline-delimited JSON request/response using the same operation names, payload schemas, and error codes where applicable.
- **Not v0.1:** WebSocket, cloud relay, public endpoint, automatic port mapping, internet discovery, remote administration, or TLS claims.

Unencrypted LAN HTTP assumes a trusted home/workshop network. The implementation must bind only intended local interfaces, reject unexpected Host/Origin values, and bound body size, parser depth, request/event rate, and timeouts. Exact limits become fixture-tested implementation constants in issue #4.

## Version and identity

- Every response/event includes `protocol_version: "0.1"`.
- Clients reject unsupported major versions and ignore documented additive fields from compatible minor versions.
- Request/response operations use a bounded opaque `request_id`; tokens and credentials never appear in URLs.
- `device_id` is random, resettable, and not derived from chip serial, MAC, SSID, or IP. Default exports omit it.
- Sequence numbers are unsigned monotonic counters within one boot/session. Reconnect always obtains a fresh status/snapshot; v0.1 does not promise durable event replay.

## Core observation

Canonical schema: [`schemas/observation-v0.1.schema.json`](schemas/observation-v0.1.schema.json)

Valid fixture: [`fixtures/observation-valid-v0.1.json`](fixtures/observation-valid-v0.1.json)

Unavailable numbers are `null`, never a reassuring zero. Each channel includes state and sample age. Environmental data becomes stale after 120 seconds without a valid sample; mass data becomes stale after 10 seconds without a valid sample. Disconnect, saturation, invalid calibration, impossible values, storage faults, and explicit out-of-range conditions remain distinct fault codes.

```json
{
  "protocol_version": "0.1",
  "device_id": "random-resettable-id",
  "sequence": 42,
  "sampled_at": null,
  "temperature_c": 23.4,
  "relative_humidity_pct": 18.2,
  "gross_mass_g": 812.0,
  "net_mass_estimate_g": 574.0,
  "stable": true,
  "calibration_state": "valid",
  "quality": {
    "environment": {"state": "fresh", "sample_age_ms": 700},
    "mass": {"state": "fresh", "sample_age_ms": 250, "uncertainty_g": null}
  },
  "faults": ["uncertainty_not_characterized"]
}
```

`sampled_at` is RFC 3339 UTC when trusted wall time exists and `null` otherwise. Sample ages use monotonic time. `uncertainty_g: null` requires the explicit `uncertainty_not_characterized` fault until bench characterization supports a value.

## LAN resources and USB operations

| Semantic operation | LAN | USB CDC | Protection |
|---|---|---|---|
| capability/status | `GET /api/v1/status` | `status` | read-only |
| current observation | `GET /api/v1/snapshot` | `snapshot` | read-only |
| live observations | `GET /api/v1/stream` (SSE) | not required | active local session; bounded rate |
| bounded aggregates | `GET /api/v1/observations` | `observations` | bounded range/page |
| add event/metadata | `POST /api/v1/events` | `event` | active presence session |
| tare/reference calibration | `POST /api/v1/calibration/{step}` | `calibrate` | active presence + explicit confirmation |
| export CSV/JSON | `GET /api/v1/export` | `export` | active local/cable session |
| backup | `GET /api/v1/backup` | `backup` | active local/cable session; credentials excluded |
| restore validation | `POST /api/v1/restore/validate` | `restore_validate` | bounded parse; no mutation |
| restore commit | `POST /api/v1/restore/commit` | `restore_commit` | fresh confirmation tied to validated digest |
| provision/recover Wi-Fi | onboarding route | `provision` | recent physical presence; credentials write-only |
| scoped deletion | `DELETE /api/v1/data` | `delete` | recent presence + fresh scope confirmation |
| factory reset | documented recovery route | `factory_reset` | cable + physical button confirmation |

## Mutation and error rules

1. The button opens a short-lived random presence session; expiry is automatic and monotonic.
2. Validation tokens bind operation, normalized payload digest, scope, and expiry. They are single-use.
3. Restore follows validate → preview → explicit commit. Current committed data remains available until the replacement transaction commits successfully.
4. Deletion names an explicit scope: `history`, `spool_metadata`, `calibration`, `network`, or `all_user_data`.
5. Errors use stable machine codes plus safe user text. Invalid/oversized/malformed input, unsupported versions, stale confirmations, and storage failures cause no mutation.
6. Wi-Fi credentials are write-only and excluded from status, diagnostics, logs, backups, exports, and support data.

## Persistence/export contract

- Store bounded validated hourly aggregates and user events; default target is rolling 90 days and the minimum is 30 complete days.
- CSV includes schema version, time basis, explicit units, quality, age, calibration state, uncertainty, and faults.
- JSON export and backup are distinct: export is portable observation/event data; backup additionally contains restorable user configuration/calibration but never network credentials.
- Integrity metadata detects accidental corruption; it is not a cryptographic authenticity claim.
- Retention and storage-full behavior are explicit and testable. Silent destruction of current committed data is forbidden.

## Implementation reconciliation (issues #4/#5)

- LAN mutation request bodies use the same bounded JSON-RPC envelope as USB operations (`request_id`, `protocol_version`, `op`, `params`) so one firmware router serves both transports (PROTO-003). Calibration LAN steps map to the `calibration_begin_tare` / `calibration_begin_reference` operations.
- Backup document envelope: `{"schema_version":"0.1","calibration_json","spool_json","events_json","checksum"}`, where `checksum` is FNV-1a 32-bit over the canonical payload `v0.1|cal:{...}|spool:{...}|events:{...}` (authoritative implementation `firmware/domain/src/backup.rs`, mirrored and contract-tested in `app/src/backup.ts`).
- The CSV export header is frozen in `firmware/domain/src/csv.rs` (`CSV_HEADER`); the companion validates every import row against it before any mutation (`app/src/csvio.ts`).
- Shared observation fixtures: `docs/fixtures/observation-valid-v0.1.json` is canonical; `app/fixtures/observation-*.json` add stale, disconnected, saturated, uncalibrated, and storage-fault cases. All must validate against `docs/schemas/observation-v0.1.schema.json` (`app/test/contract.test.ts`).
- Deletion scopes match the enumerated values in mutation rule 4 (`history`, `spool_metadata`, `calibration`, `network`, `all_user_data`); the UI never fabricates the device-issued confirmation token.
- `GET /api/v1/status` payload minimum fields are listed in `app/src/client.ts` (`StatusPayload`, additive-tolerant); the firmware finalizes the exact shape with the LAN adapter in issue #6.

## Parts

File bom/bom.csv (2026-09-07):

References | Qty | Value | Manufacturer | MPN | Footprint | Datasheet | Supplier | Supplier PN | Estimated Unit Cost USD | Price Observed UTC | Stock Observed | Lifecycle Status | Lifecycle/Availability Evidence UTC | Alternate MPN / Source | Cost Basis | BOM Comments
C1 | 1 | 4.7uF 10V X5R | Murata | GRM31CR61A475KA01L | Capacitor_SMD:C_1206_3216Metric | https://www.murata.com/en-global/products/capacitor/mlcc/overview/lineup | DigiKey | 490-3902-1-ND | 0.20 | 2026-08-21 | Not verified — distributor API credentials unavailable | Lifecycle not machine-verified; check manufacturer PCN/EOL sources before release | 2026-08-21 |  | Public distributor listing/search estimate; not a quote | Protected 5 V bulk capacitor; total carrier input capacitance remains below 10 uF nominal.
C2, C4, C10 | 3 | 100nF 50V X7R | Murata | GRM188R71H104KA93D | Capacitor_SMD:C_0603_1608Metric | https://search.murata.co.jp/Ceramy/image/img/A01X/G101/ENG/GRM188R71H104KA93-01.pdf | DigiKey | 490-1519-1-ND | 0.02 | 2026-08-21 | Not verified — distributor API credentials unavailable | Lifecycle not machine-verified; check manufacturer PCN/EOL sources before release | 2026-08-21 |  | Public distributor listing/search estimate; not a quote | High-frequency bypass on protected 5 V rail.; High-frequency bypass on the 3V3 rail.; Button hardware debounce; firmware still applies bounded debounce and long-press timing.
C3 | 1 | 10uF 10V X5R | Murata | GRM31CR61A106KA01L | Capacitor_SMD:C_1206_3216Metric | https://search.murata.co.jp/Ceramy/image/img/A01X/G101/ENG/GRM31CR61A106KA01-01.pdf | LCSC | C97949 | 0.3351 | 2026-08-21 | 22 | Lifecycle not machine-verified; check manufacturer PCN/EOL sources before release | 2026-08-21 |  | 1 @ $0.3351 | Local bulk capacitor on the XIAO 3V3 output; regulator is on the module.
C5, C6 | 2 | 1uF 16V X7R | Murata | GRM188R71C105KA12D | Capacitor_SMD:C_0603_1608Metric | https://www.murata.com/en-global/products/capacitor/mlcc/overview/lineup | DigiKey | TBD—verify before order | 0.08 | 2026-08-21 | Not verified — distributor API credentials unavailable | Lifecycle not machine-verified; check manufacturer PCN/EOL sources before release | 2026-08-21 |  | Public distributor listing/search estimate; not a quote | DVDD local bypass; Nuvoton Rev. 2.6 p.24.; AVDD/LDO local bypass; low-ESR, Nuvoton Rev. 2.6 pp.6,24.
C7, C8 | 2 | 100nF 50V X7R | Murata | GRM188R71H104KA93D | Capacitor_SMD:C_0603_1608Metric | https://www.murata.com/en-global/products/capacitor/mlcc/overview/lineup | DigiKey | TBD—verify before order | 0.02 | 2026-08-21 | Not verified — distributor API credentials unavailable | Lifecycle not machine-verified; check manufacturer PCN/EOL sources before release | 2026-08-21 |  | Public distributor listing/search estimate; not a quote | VBG bypass per Nuvoton Rev. 2.6 p.24.; Differential bridge-input filter after the two 47 Ω series resistors.
C9 | 1 | 330pF 50V C0G | Murata | GRM1885C1H331JA01D | Capacitor_SMD:C_0603_1608Metric | https://www.murata.com/en-global/products/capacitor/mlcc/overview/lineup | DigiKey | TBD—verify before order | 0.05 | 2026-08-21 | Not verified — distributor API credentials unavailable | Lifecycle not machine-verified; check manufacturer PCN/EOL sources before release | 2026-08-21 |  | Public distributor listing/search estimate; not a quote | Optional PGA-output Cfilter between VIN2P and VBG; enable PGA_CAP_EN; Nuvoton p.24.
C11 | 1 | 1uF 16V X7R | Murata | GRM188R71C105KA12D | Capacitor_SMD:C_0603_1608Metric | https://www.murata.com/en-global/products/capacitor/mlcc/overview/lineup | DigiKey | 490-3897-1-ND | 0.08 | 2026-08-21 | Not verified — distributor API credentials unavailable | Lifecycle not machine-verified; check manufacturer PCN/EOL sources before release | 2026-08-21 |  | Public distributor listing/search estimate; not a quote | Local VBUS input bypass; total nominal input capacitance remains below 10 uF.
D1 | 1 | SMF5.0A | Littelfuse | SMF5.0A | Diode_SMD:D_SOD-123F | https://www.littelfuse.com/assetdocs/tvs-diodes-smf-datasheet?assetguid=7eb8a5b6-bdd0-4561-8f19-0c3cc6f9b2af | DigiKey | F8583CT-ND | 0.30 | 2026-08-21 | Not verified — distributor API credentials unavailable | Lifecycle not machine-verified; check manufacturer PCN/EOL sources before release | 2026-08-21 |  | Public distributor listing/search estimate; not a quote | VBUS transient clamp; place at J1 with short return to ground.
D2 | 1 | B140-13-F | Diodes Incorporated | B140-13-F | Diode_SMD:D_SMA | https://www.diodes.com/assets/Datasheets/ds13002.pdf | LCSC | C15759 | 0.0856 | 2026-08-21 | 59660 | Lifecycle not machine-verified; check manufacturer PCN/EOL sources before release | 2026-08-21 |  | 5 @ $0.0856 each | Series reverse-current block prevents carrier USB input from being back-fed by U1 USB.
D3 | 1 | RGB STATUS | Broadcom Limited | ASMT-YTC7-0AA02 | LED_SMD:LED_Avago_PLCC6_3x2.8mm | https://docs.broadcom.com/docs/AV02-3819EN | JLCPCB | C5555828 | 1.7772 | 2026-08-22 | 79 | Lifecycle not machine-verified; check manufacturer PCN/EOL sources before release | 2026-08-22 |  | 1 @ $1.7772; JLCPCB extended part | Current YTC7 replacement for obsolete YTC2. Datasheet lead map: 1 KB, 2 KG, 3 KR, 4 AR, 5 AG, 6 AB. Independently driven active-low cathodes; text/icon fault detail remains in the PWA.
F1 | 1 | 500mA hold | Bourns | MF-MSMF050-2 | Fuse:Fuse_1812_4532Metric | https://www.bourns.com/docs/product-datasheets/mf-msmf.pdf | LCSC | C17313 | 0.0668 | 2026-08-21 | 47400 | Lifecycle not machine-verified; check manufacturer PCN/EOL sources before release | 2026-08-21 |  | 10 @ $0.0668 each | 500 mA hold / 1 A trip PPTC; preserves <500 mA normal-current design target.
J1 | 1 | USB-C POWER ONLY | Global Connector Technology | USB4105-GF-A | Connector_USB:USB_C_Receptacle_GCT_USB4105-xx-A_16P_TopMnt_Horizontal | https://gct.co/files/drawings/usb4105.pdf | LCSC | C3020560 | 1.0659 | 2026-08-21 | 926 | Lifecycle not machine-verified; check manufacturer PCN/EOL sources before release | 2026-08-21 |  | 1 @ $1.0659 | Power-only UFP. CC1/CC2 each use 5.1k Rd. D+/D-/SBU are intentionally NC. Shell to GND.
J2 | 1 | LOAD CELL E+/E-/S+/S- | JST | SM04B-GHS-TB(LF)(SN) | Connector_JST:JST_GH_SM04B-GHS-TB_1x04-1MP_P1.25mm_Horizontal | https://www.jst-mfg.com/product/pdf/eng/eGH.pdf | LCSC | C189895 | 1.1182 | 2026-08-21 | 0 | Lifecycle not machine-verified; check manufacturer PCN/EOL sources before release | 2026-08-21 |  | 1 @ $1.1182; out of stock | Keyed carrier connector. Pin 1 E+, 2 E-, 3 S+ (green), 4 S- (white). LCSC C189895 was out of stock when checked; verify DigiKey/alternate stock before ordering. Mating housing and contacts are external BOM items.
J3 | 1 | UART DEBUG 3V3 | Samtec | TSW-104-07-G-S | Connector_PinHeader_2.54mm:PinHeader_1x04_P2.54mm_Vertical | https://suddendocs.samtec.com/prints/tsw-1xx-xx-xxx-x-xx-xx-mkt.pdf | JLCPCB | C3335156 | 0.6472 | 2026-08-21 | 337 | Lifecycle not machine-verified; check manufacturer PCN/EOL sources before release | 2026-08-21 |  | 1 @ $0.6472 | Optional 3.3 V UART header: pin 1 3V3, 2 GND, 3 TX (D6/GPIO21), 4 RX (D7/GPIO20). Do not apply 5 V logic.
R1, R2 | 2 | 5.1k 1% | Yageo | RC0603FR-075K1L | Resistor_SMD:R_0603_1608Metric | https://www.yageo.com/upload/media/product/productsearch/datasheet/rchip/PYu-RC_Group_51_RoHS_L_16.pdf | DigiKey | 311-5.10KHRCT-ND | 0.02 | 2026-08-21 | Not verified — distributor API credentials unavailable | Lifecycle not machine-verified; check manufacturer PCN/EOL sources before release | 2026-08-21 |  | Public distributor listing/search estimate; not a quote | USB-C CC1 Rd; 5.1 kΩ to GND per USB Type-C sink power role.; USB-C CC2 Rd; 5.1 kΩ to GND per USB Type-C sink power role.
R3, R4 | 2 | 47R 1% | Yageo | RC0603FR-0747RL | Resistor_SMD:R_0603_1608Metric | https://www.yageo.com/upload/media/product/productsearch/datasheet/rchip/PYu-RC_Group_51_RoHS_L_16.pdf | DigiKey | 311-47.0HRCT-ND | 0.02 | 2026-08-21 | Not verified — distributor API credentials unavailable | Lifecycle not machine-verified; check manufacturer PCN/EOL sources before release | 2026-08-21 |  | Public distributor listing/search estimate; not a quote | Bridge input series filter resistor per Nuvoton Rev. 2.6 p.24.
R5, R6 | 2 | 4.7k 1% | Yageo | RC0603FR-074K7L | Resistor_SMD:R_0603_1608Metric | https://www.yageo.com/upload/media/product/productsearch/datasheet/rchip/PYu-RC_Group_51_RoHS_L_16.pdf | DigiKey | 311-4.70KHRCT-ND | 0.02 | 2026-08-21 | Not verified — distributor API credentials unavailable | Lifecycle not machine-verified; check manufacturer PCN/EOL sources before release | 2026-08-21 |  | Public distributor listing/search estimate; not a quote | Carrier-owned 3.3 V I2C pull-up; do not parallel strong module pull-ups.
R7 | 1 | 10k 1% | Yageo | RC0603FR-0710KL | Resistor_SMD:R_0603_1608Metric | https://www.yageo.com/upload/media/product/productsearch/datasheet/rchip/PYu-RC_Group_51_RoHS_L_16.pdf | DigiKey | 311-10.0KHRCT-ND | 0.02 | 2026-08-21 | Not verified — distributor API credentials unavailable | Lifecycle not machine-verified; check manufacturer PCN/EOL sources before release | 2026-08-21 |  | Public distributor listing/search estimate; not a quote | External pull-up for dedicated active-low button.
R8, R9, R10 | 3 | 220R 1% | Yageo | RC0603FR-07220RL | Resistor_SMD:R_0603_1608Metric | https://www.yageo.com/upload/media/product/productsearch/datasheet/rchip/PYu-RC_Group_51_RoHS_L_16.pdf | LCSC | C107696 | 0.0061 | 2026-08-21 | 417400 | Lifecycle not machine-verified; check manufacturer PCN/EOL sources before release | 2026-08-21 |  | 100 @ $0.0061 each | RGB channel current limiting; final brightness/current is a bench-verification item.
SW1 | 1 | TARE/CAL/RECOVERY | C&K (Littelfuse) | PTS810SJM250SMTRLFS | Button_Switch_SMD:SW_SPST_PTS810 | https://www.ckswitches.com/media/1476/pts810.pdf | DigiKey | CKN10502CT-ND | 0.20 | 2026-08-21 | Not verified — distributor API credentials unavailable | Lifecycle not machine-verified; check manufacturer PCN/EOL sources before release | 2026-08-21 |  | Public distributor listing/search estimate; not a quote | Dedicated user button, active low; firmware differentiates short/long hold. Not the XIAO BOOT/RESET control.
U1 | 1 | Seeed XIAO ESP32-C3 | Seeed Technology Co., Ltd. | 113991054 | spool-sentry:XIAO_ESP32C3 | https://files.seeedstudio.com/Bazaar/product_pdf/113991054.pdf | Seeed Studio | 113991054 | 4.99 | 2026-08-21 | Not verified — distributor API credentials unavailable | Lifecycle not machine-verified; check manufacturer PCN/EOL sources before release | 2026-08-21 |  | Public distributor listing/search estimate; not a quote | Module USB-C is the supported programming/recovery port; battery pads are DNP/unused.
U2 | 1 | NAU7802SGI | Nuvoton Technology Corporation | NAU7802SGI | Package_SO:SOIC-16_3.9x9.9mm_P1.27mm | https://www.nuvoton.com/export/resource-files/en-us--DS_NAU7802_DataSheet_EN_Rev2.6.pdf | LCSC | C5180029 | 1.7781 | 2026-08-21 | 1427 | Lifecycle not machine-verified; check manufacturer PCN/EOL sources before release | 2026-08-21 |  | 1 @ $1.7781 | Configure internal LDO for 3.0 V AVDD, channel 1, PGA128, internal RC, 10 SPS; check CAL_ERR.
U3 | 1 | SHT40-N-NF | Sensirion AG | SHT40-N-NF | Package_DFN_QFN:DFN-4_1.5x1.5mm_P0.8mm | https://sensirion.com/media/documents/33FD6951/6555C40E/Sensirion_Datasheet_SHT4x.pdf | LCSC | C54946589 | 0.9568 | 2026-09-05 | 1652 | Lifecycle not machine-verified; check manufacturer PCN/EOL sources before release | 2026-09-05 |  | LCSC listing at 1pc: $0.9568 | Humidity+temperature sensing path over I2C. SHT4x pin assignment (datasheet Fig. 18 top view): 1=SDA, 2=SCL, 3=VDD, 4=VSS.

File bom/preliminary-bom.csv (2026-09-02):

Item | Qty | Function | Candidate_Class_or_Family | Package_or_Module | Manufacturer | MPN | Supplier_or_Source | Estimated_Unit_Cost_USD | Planning_Status | Notes
Controller | 1 | Wi-Fi MCU and local application host | ESP32-C3 module family | Castellated RF module | TBD | TBD | TBD | TBD - live sourcing required | PLANNING_ONLY | Exact module and antenna variant require manufacturer integration review
Environmental sensor | 1 | Temperature and relative-humidity observation | Digital humidity/temperature sensor family | SMD or serviceable module | TBD | TBD | TBD | TBD - live sourcing required | PLANNING_ONLY | Select for accuracy drift response condensation limits and placement guidance
Load-cell ADC | 1 | Bridge excitation and low-noise conversion | 24-bit load-cell ADC family | SMD IC or prototype module | TBD | TBD | TBD | TBD - live sourcing required | PLANNING_ONLY | Selection must document gain rate noise supply and input limits
Load cell | 1 | Spool platform force sensing | Bar load cell 5 kg class | Four-wire bar sensor | TBD | TBD | TBD | TBD - live sourcing required | PLANNING_ONLY | Final rated load and mounting geometry require mechanical validation
USB connector | 1 | 5 V power and data | USB Type-C receptacle family | SMD connector | TBD | TBD | TBD | TBD - live sourcing required | PLANNING_ONLY | Select hand-assembly-compatible candidate with verified footprint
Input protection | 1 | USB input ESD and fault protection | Low-voltage protection network | SMD devices | TBD | TBD | TBD | TBD - live sourcing required | PLANNING_ONLY | Topology and ratings depend on selected USB and power architecture
Voltage regulation | 1 | Generate controller and sensor rail | 3.3 V regulator family | SMD IC | TBD | TBD | TBD | TBD - live sourcing required | PLANNING_ONLY | Exact need current and thermal margin depend on selected module
Passives | 1 lot | Decoupling bias filtering and indication | Resistor capacitor ferrite and LED classes | Mixed SMD | TBD | TBD | TBD | TBD - live sourcing required | PLANNING_ONLY | Values packages ratings and quantities come from schematic and datasheets
Buttons | 1 | Physical setup tare and confirmation | Momentary switch family | Through-hole or SMD | TBD | TBD | TBD | TBD - live sourcing required | PLANNING_ONLY | Must remain accessible with non-color-only status feedback
Connectors and test access | 1 lot | Load-cell sensor debug and measurements | Keyed headers terminals and test points | Mixed | TBD | TBD | TBD | TBD - live sourcing required | PLANNING_ONLY | Include mating parts and strain relief after interface freeze
Carrier PCB | 1 | Mount and interconnect electronics | Two-layer custom PCB | KiCad fabrication | TBD | TBD | TBD | TBD - fabrication quote required | PLANNING_ONLY | No design or fabrication quote exists yet
Platform and enclosure | 1 set | Support spool and protect electronics | Editable printed or fabricated mechanics | Mechanical assembly | TBD | TBD | TBD | TBD - live sourcing required | PLANNING_ONLY | Material geometry ventilation and fasteners remain design tasks
USB cable and suitable supply | 1 set | Provide external SELV 5 V power and host data | Commercial cable and enclosed supply | External item | TBD | TBD | TBD | TBD - live sourcing required | PLANNING_ONLY | Use suitable certified supply and data-capable cable; not part of schematic
Fasteners and load-cell spacers | 1 set | Mechanical assembly and force path | Common screws inserts washers and spacers | Mechanical hardware | TBD | TBD | TBD | TBD - live sourcing required | PLANNING_ONLY | Final sizes and quantities depend on editable mechanical design
Calibration reference | 1 | Known mass for calibration workflow | User-provided traceable-enough hobby reference | External item | TBD | TBD | TBD | TBD - live sourcing required | PLANNING_ONLY | Document actual reference and uncertainty; not included in electronics cost target

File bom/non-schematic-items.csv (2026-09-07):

Item | Qty | Category | Specification / MPN | Source | Notes
Carrier PCB fabrication | 1 | Manufacturing | TBD (2-layer FR-4 | final fab stack-up not yet frozen) | Fabricator quote required | Not represented as a schematic symbol.
Carrier PCB assembly | 1 | Manufacturing | TBD (SMT assembly service) | Assembler quote required | Not represented as a schematic symbol.
Passive dry-box enclosure | 1 | Mechanical | TBD (sealed dry-box enclosure sized for spool + carrier) | Integrator-defined | Required for passive moisture-control deployment; enclosure dimensions finalized in Issue #3.
USB-C cable | 1 | Accessory | USB 2.0 or better A-to-C / C-to-C cable | Distributor/open market | Needed for commissioning and power.
5 V USB SELV supply | 1 | Accessory | 5 V regulated USB wall supply (<500 mA continuous target) | Distributor/open market | External supply; not represented as a schematic symbol.
Calibration reference mass set | 1 | Calibration | Known reference masses (for example 500 g + 1000 g) | Metrology supplier | Required for NAU7802 scale calibration and drift checks.
JST GH mating housing | 1 | Connector accessory | GHR-04V-S | JST/distributor | Required mate for J2 cable harness; external harness BOM item.
JST GH crimp contacts | 4 | Connector accessory | SSHL-002T-P0.2 | JST/distributor | Required mate for J2 cable harness; external harness BOM item.
Load-cell cable/harness | 1 | Harness | 4-conductor load-cell harness (E+/E-/S+/S-) | Integrator-defined | Mechanical length/strain relief is enclosure-specific.
Load-cell mechanical mounting kit | 1 | Mechanical | TBD (bracket/fixture + fasteners) | Integrator-defined | Depends on selected load-cell geometry and enclosure.
Carrier mounting hardware set | 1 | Mechanical | TBD (standoffs/screws/washers sized after enclosure release) | Integrator-defined | Final dimensions depend on enclosure and hole plan (Issue #3).

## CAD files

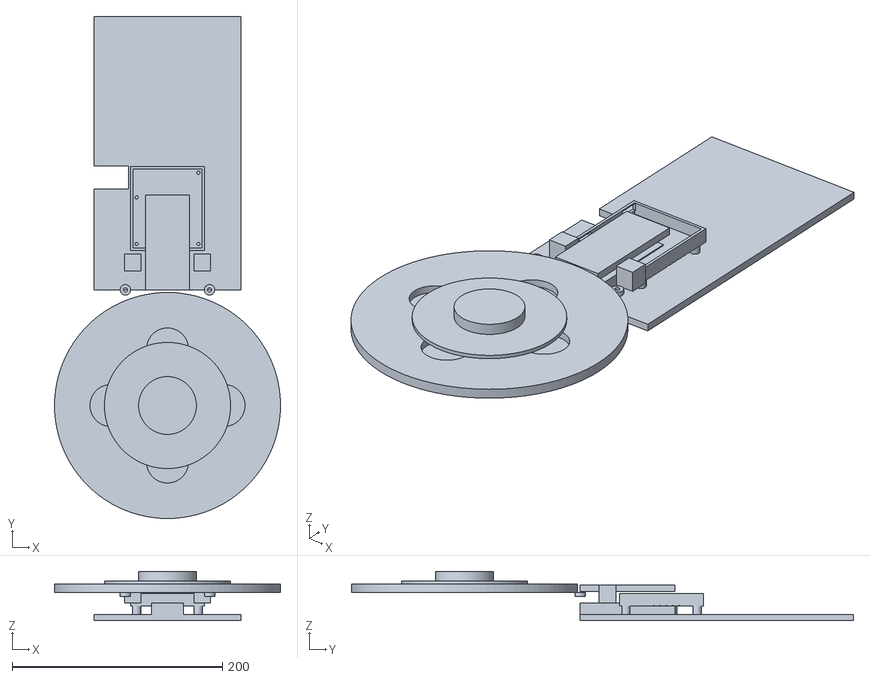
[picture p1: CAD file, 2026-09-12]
mechanical/preview-assembly.stl
215.0 x 477.5 x 47.0

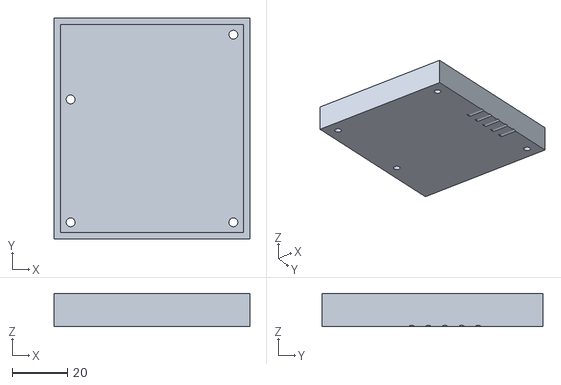
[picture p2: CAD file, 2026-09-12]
mechanical/spool-sentry-tray.stl
70.8 x 79.8 x 12.0

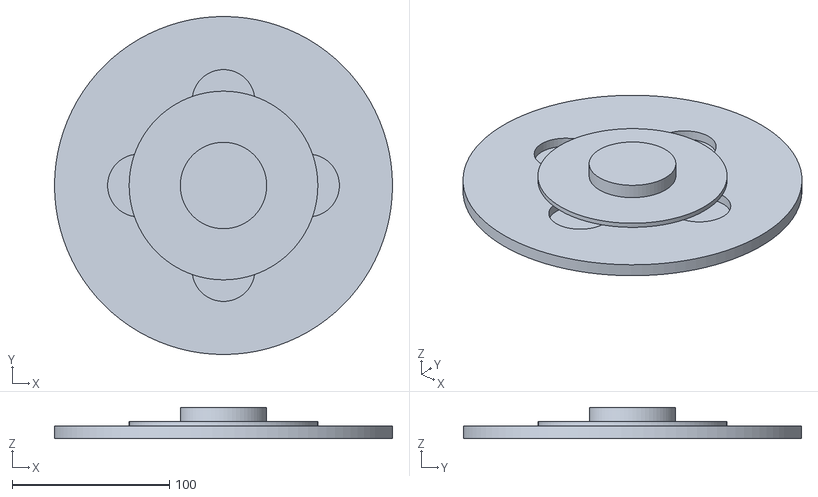
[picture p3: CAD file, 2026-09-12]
mechanical/spool-sentry-platform.stl
215.0 x 215.0 x 20.0

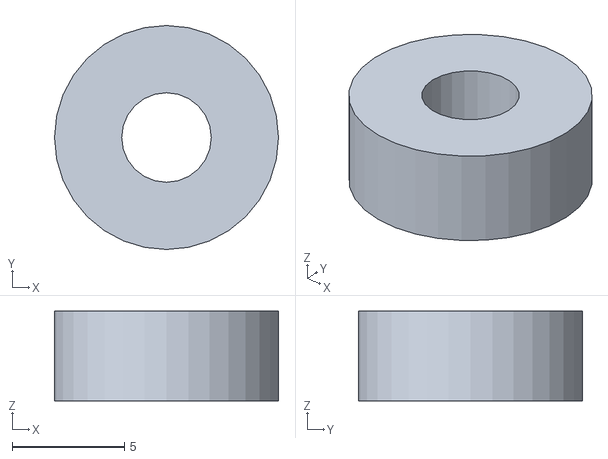
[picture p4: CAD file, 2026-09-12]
mechanical/spool-sentry-stop.stl
10.0 x 10.0 x 4.00

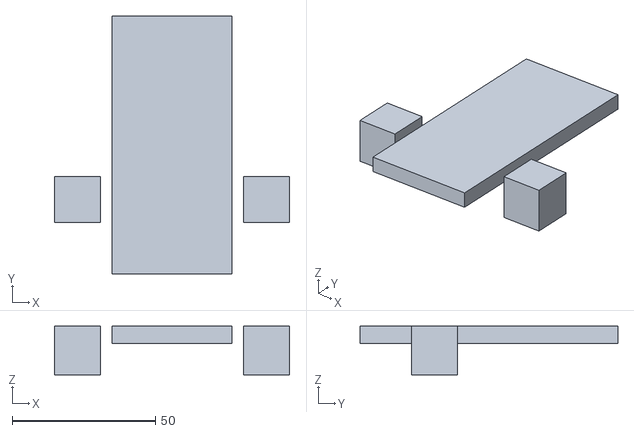
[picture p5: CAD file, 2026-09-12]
mechanical/spool-sentry-bracket.stl
82.0 x 90.0 x 17.0

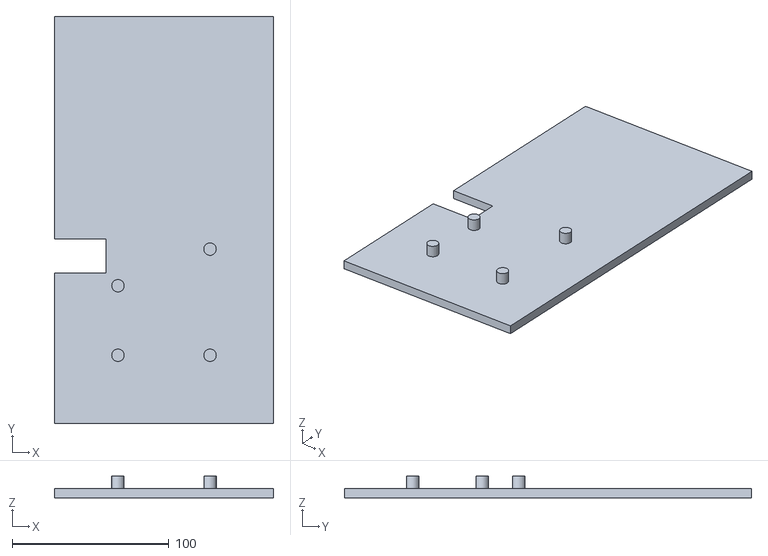
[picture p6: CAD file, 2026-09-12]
mechanical/spool-sentry-base.stl
140.0 x 260.0 x 14.0

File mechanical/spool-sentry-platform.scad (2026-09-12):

// ============================================================
// Spool Sentry — one-spool platform + force path (issue #3)
// Editable OpenSCAD source. Review-only geometry: NOTHING here
// has been printed, fitted, or load-tested. See
// docs/verification/issue-3-pcb.md ("Mechanical evidence").
//
// Force path (per docs/architecture.md "Mechanical force path"):
//   spool -> removable platform -> platform bracket -> FIXED end
//   of a replaceable >=5 kg bar load cell -> base plate.
// The electronics carrier tray bolts to the base plate and is
// mechanically isolated from the moving load path.
//
// Safety boundary: USB 5 V SELV, observation only. No actuation,
// no mains, no safety claim, no certified measurement.
// ============================================================

// ---- Load cell envelope (PARAMETRIC — no MPN is frozen) ----
// The BOM carries a "replaceable >=5 kg bar load cell" with geometry
// finalized only when an exact part is selected (issue #6). These
// defaults are an ASSUMED generic bar-cell envelope and MUST be set
// from the chosen cell's datasheet drawing before fabrication.
cell_length   = 90;    // [mm] bar length  (ASSUMED)
cell_width    = 30;    // [mm] bar width   (ASSUMED)
cell_height   = 11;    // [mm] bar height  (ASSUMED)
cell_hole_pitch = 66;  // [mm] mounting-hole pitch (ASSUMED)
cell_hole_d   = 6.6;   // [mm] M5 clearance hole   (ASSUMED)
cell_bolt_d   = 5.0;   // [mm] M5 bolt
rated_kg      = 5;     // datasheet rated capacity used for stop design

// ---- Working / overload envelope (MECH-001, MEAS-002) ----
working_kg    = 2.5;   // centered static working load
deflection_mm = 1.0;   // expected tip deflection at working load (ASSUMED; bench item)
stop_gap_mm   = 3.0;   // hard-stop gap above working deflection; overload
                       // transfers through the stopposts, not the cell.
                       // Stop design is a bench-verification item before
                       // any publication claim.

// ---- Spool fit envelope (MECH-004) ----
// Envelope for "common" filament spools only — this is NOT a universal
// fit claim. Typical market envelope ~Ø205 x 70 mm max.
spool_od      = 205;   // [mm] envelope outer diameter
spool_width   = 70;    // [mm] envelope width
hub_bore      = 55;    // [mm] centering spigot (common hub bore; not universal)

// ---- Carrier PCB envelope (matches hardware/spool-sentry.kicad_pcb) ----
pcb_w = 66;  // board X
pcb_l = 75;  // board Y
pcb_t = 1.6;
m3_d  = 3.2;
// M3 hole centers on the board (mm, board origin at corner):
pcb_holes = [[3.6,3.6],[62.4,3.6],[62.4,71.4],[3.6,48.0]];

// ---- Generic helpers ----------------------------------------
module clear_hole(d, h) { cylinder(h=h, d=d, $fn=48); }

// ============================================================
// 1) Base plate — the fixed half of the force path.
//    Load cell bolts down at one end; carrier tray bolts flat.
// ============================================================
module base_plate() {
    L = 260; W = 140; t = 6;
    difference() {
        union() {
            translate([-W/2, 0, -t]) cube([W, L, t], center=false);
            // load-cell mounting pads at the fixed end
            for (dx = [-cell_hole_pitch/2, cell_hole_pitch/2])
                translate([dx, 18, -t])
                    linear_extrude(t)
                        offset(r=6) circle(d=cell_hole_d, $fn=32);
            // carrier-tray standoff bosses (M3), pattern mirrors the PCB
            for (h = pcb_holes)
                translate([h[0]-pcb_w/2, 40 + h[1], -t])
                    linear_extrude(6+8)
                        circle(d=8, $fn=32);
        }
        // bolt holes through cell pads
        for (dx = [-cell_hole_pitch/2, cell_hole_pitch/2])
            translate([dx, 18, -t-1]) rotate([90,0,0])
                clear_hole(cell_bolt_d, t+2);
        // M3 tapped holes in tray bosses (pilot 2.5 mm)
        for (h = pcb_holes)
            translate([h[0]-pcb_w/2, 40 + h[1], -t-1]) rotate([90,0,0])
                clear_hole(2.5, t+8+2);
        // cable slot for load-cell harness + USB exit (strain relief path)
        translate([-W/2-1, 96, -t-1]) cube([34, 22, t+2]);
    }
}

// ============================================================
// 2) Platform — the moving half. Removable (MECH-002): it simply
//    rests on the platform bracket; the load path is compression
//    through the bracket on the cell's fixed end.
// ============================================================
module platform() {
    pd = spool_od + 10;      // platform disc with 5 mm margin
    t  = 8;
    difference() {
        union() {
            cylinder(h=t, d=pd, $fn=96);
            // centering spigot for common hub bores
            translate([0,0,t]) cylinder(h=12, d=hub_bore, $fn=64);
            // load pad under spool rim/face
            translate([0,0,t]) cylinder(h=3, d=120, $fn=96);
        }
        // lightening pockets (keep rim stiff; bench item for stiffness)
        for (a = [0:90:270]) rotate([0,0,a])
            translate([pd/4, 0, 2]) cylinder(h=t-2, d=40, $fn=48);
    }
}

// ============================================================
// 3) Platform bracket + overload stop. Bracket transfers platform
//    load to the cell's free end; stopposts limit travel so an
//    overload path exists before the cell yields (bench item).
// ============================================================
module cell_bracket() {
    // U-bracket clamping the cell free end (bolted, hand tools)
    bw = cell_width + 12; bl = cell_length; bt = 6;
    difference() {
        union() {
            // floor over cell
            translate([-bw/2, 0, cell_height]) cube([bw, bl, bt], center=false);
            // side wings bolting to cell top holes
            for (dx = [-cell_hole_pitch/2, cell_hole_pitch/2])
                translate([dx-8, 18, 0]) cube([16, 16, cell_height+bt]);
        }
        // cell body clearance
        translate([-cell_width/2-0.5, 0, -1]) cube([cell_width+1, bl, cell_height+1]);
        for (dx = [-cell_hole_pitch/2, cell_hole_pitch/2])
            translate([dx, 18, cell_height+bt+1]) rotate([90,0,0])
                clear_hole(cell_bolt_d, cell_height+bt+2);
    }
}

module overload_stop_post(h) {
    // fixed post; platform/bracket top must clear this by `h`.
    // Gap = deflection_mm + stop_gap_mm above working position.
    difference() {
        cylinder(h=h, d=10, $fn=32);
        translate([0,0,h-4]) cylinder(h=5, d=4, $fn=24);
    }
}

// ============================================================
// 4) Carrier tray — mechanically ISOLATED from load path (per
//    architecture). Holds the 66x75 PCB on M3 standoffs; vents at
//    the SHT40 corner; USB + load-cell cables route down the slot.
// ============================================================
module carrier_tray() {
    wall = 2.4; floor_t = 2;
    x0 = -pcb_w/2 - wall; y0 = -wall; x1 = pcb_w/2 + wall; y1 = pcb_l + wall;
    difference() {
        union() {
            translate([x0, y0, 0]) cube([x1-x0, y1-y0, floor_t]);
            // walls (10 mm) on all sides
            translate([x0, y0, floor_t]) cube([x1-x0,  wall, 10]);
            translate([x0, y1-wall, floor_t]) cube([x1-x0, wall, 10]);
            translate([x0, y0, floor_t]) cube([wall, y1-y0, 10]);
            translate([x1-wall, y0, floor_t]) cube([wall, y1-y0, 10]);
        }
        // M3 standoff holes matching the board
        for (h = pcb_holes)
            translate([h[0]-pcb_w/2, h[1], -1])
                clear_hole(m3_d, floor_t+2);
        // USB port access at board edge (J1 at y≈68, x≈0 board coords)
        translate([-pcb_w/2-wall-1, 60, floor_t+3]) cube([wall+2, 16, 6]);
        // load-cell harness slot (J2 at y≈13, x≈0)
        translate([-pcb_w/2-wall-1, 6, floor_t+3]) cube([wall+2, 14, 6]);
        // vents at U3/SHT40 corner (board corner 62,44 -> tray coords)
        for (i = [0:4])
            translate([pcb_w/2-6, 30+i*6, -1]) rotate([0,90,0])
                clear_hole(3, wall*2+80);
    }
}

// ---- Sensor heat-separation note (MECH-003): U3 sits in the far
// corner of the board from U1/regulators (~38 mm on PCB; carrier
// tray vents on the same corner wall). Bring-up comparison in #6.
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

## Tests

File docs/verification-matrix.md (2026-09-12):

# Requirements verification matrix

Evidence states: **planned**, **pass**, **fail**, **blocked**, or **not applicable**. This baseline intentionally records mostly planned evidence. Target-build proof is not bench evidence.

| Requirement | Planned method | Acceptance evidence | Current state |
|---|---|---|---|
| PRD-001 | Static architecture + schematic/PCB inspection | One load-cell channel and one environmental channel; no inventory channel | pass (schematic path implements one NAU7802 bridge channel + one SHT40 channel) |
| PRD-002 | Static schematic/PCB/protocol review | No actuator/power-control interface or command | pass (static schematic/protocol review; no actuator nets or control drivers) |
| PRD-003 | Static code/network review + offline integration | Core flows work without account/cloud/internet; no telemetry | planned |
| PWR-001 | Datasheet review, ERC/DRC, bench | Protected SELV-only input and measured rails | pass (static ERC + protection path present; bench rail measurements pending) |
| PWR-002 | Calculation + PCB current analysis + bench | Worst-case/inrush budget and ≥20% path margin | planned |
| PWR-003 | Host fixtures + bench fault injection | Every listed failure emits explicit invalid/fault state | planned |
| MEAS-001 | Datasheet review + environmental comparison | Range/status/age/accuracy metadata and recorded comparison | planned |
| MEAS-002 | Datasheet/mechanical review + bench loads | 0–2.5 kg centered operation with ≥5 kg rated cell | planned |
| MEAS-003 | Bench repeats | Raw trials from 100 g–2.0 kg meet greater-of limit | planned |
| MEAS-004 | UI/unit tests + bench-derived precision review | Display increment no finer than supporting evidence | planned |
| MEAS-005 | UI/unit tests + bench-derived precision review | Formula, assumptions, uncertainty, and negative fault behavior | pass (host: net=gross−tare with user-entered tare, null uncertainty + explicit fault; UI half now covered by `app/test/format.test.ts` host tests — no-zero nulls, uncertainty fault text; browser matrix deferred to #6) |
| MEAS-006 | Schema/migration/fault tests | Complete record and invalidation transitions | planned |
| MECH-001 | CAD/static review + progressive bench load | No PCB/enclosure contact at centered 2.5 kg | planned (editable OpenSCAD force-path source + overload stop geometry committed in issue #3; geometry is review-only — no print, fit check, or load test performed) |
| MECH-002 | Assembly inspection | Listed items replaceable with ordinary tools | planned (issue #3 CAD provides bolted/replaceable interfaces; assembly inspection not performed) |
| MECH-003 | PCB/mechanical/thermal review + bench comparison | Documented spacing/airflow and heat-bias observations | planned (issue #3 places U3 in the far corner ≥ ~38 mm from U1 with vented tray corner documented; no thermal simulation or bench comparison performed) |
| MECH-004 | Source/release inspection | Editable mechanics and bounded spool envelope | pass (editable `mechanical/spool-sentry-platform.scad` + STL previews committed; Ø205×70 mm "common spool" envelope explicitly non-universal) |
| DATA-001 | Capacity/wear calculation + host/target storage test | ≥30 days; measured 90-day default target behavior | planned |
| DATA-002 | Schema/privacy/round-trip tests | Valid versioned CSV/JSON with no prohibited identifiers | pass (host: backup envelope has no credential field and CSV rows carry version/time-basis/units/quality; target round-trip deferred to #6) |
| DATA-003 | Host property/fault tests | Validate/preview/commit and interruption preserve prior state | pass (host: validate→commit and interrupted staging fall back to committed copy) |
| DATA-004 | Host/UI/USB tests | Each scope deletes exactly requested data after confirmation | pass (host: confirmed deletion scopes erase exactly their keys; companion UI lists the exact protocol scopes, requires confirmation, and never fabricates the device token; USB/on-device halves deferred to #6) |
| DATA-005 | Host fault injection + target storage test | Corruption/full/interruption/retention are bounded and explicit | pass (host: checksum-corrupt read falls back, capacity-exceeded evicts oldest explicitly, retention window enforced; target storage deferred to #6) |
| CONN-001 | Protocol contract + target integration | Local HTTP JSON and SSE; no WebSocket/remote endpoint | planned |
| CONN-002 | Host timing/security + bench button tests | Presence session is random, recent, bounded, and expires | pass (host: nonce session, freshness window, auto-expiry; bench button timing deferred to #6) |
| CONN-003 | USB fixtures + target/bench integration | Required offline command subset works without Wi-Fi/internet | planned |
| CONN-004 | Static dependency/network/permission review | No prohibited network service or phone permission | planned |
| SEC-001 | Protocol fuzz/bounds tests + LAN inspection | Host/Origin rejection and enforced size/rate/time limits | pass (host: size/depth caps, rate budget, malformed-input non-mutation enforced by the shared router; Host/Origin binding lands with the LAN adapter in #6) |
| SEC-002 | Log/export/backup inspection | No credentials/stable hardware/network IDs; resettable ID | pass (host: backup structurally excludes credentials; error text is static safe text; device id random/resettable) |
| PROTO-001 | Schema/contract compatibility tests | 0.1 payloads accepted; unsupported major rejected | pass (host: protocol const enforced, unsupported version rejected before dispatch) |
| PROTO-002 | `scripts/check_docs.py` + UI fixtures | Observation schema/fixture valid; quality always explicit | pass (static schema fixture; companion contract tests validate repo + app fault fixtures against the same schema in `app/test/contract.test.ts`) |
| PROTO-003 | Host parser/import tests | LAN/USB semantics match; malformed input causes no mutation | pass (host: one shared router serves both transports; malformed frames return errors and never mutate state) |
| FW-001 | Clean host test + ESP32-C3 release build | Pinned toolchain, host tests, linked target image | pass (pinned toolchain, domain host tests, linked domain ELF; see `firmware/domain`) |
| FW-002 | Host unit/property tests with fakes | Domain behaviors run without physical hardware | pass (host: 74 unit + 3 fixture-contract tests in `firmware/domain` with injected adapter fakes) |
| UX-001 | Automated/manual accessibility + browser smoke | Keyboard/SR/focus/zoom/motion/contrast/table evidence | planned (host/jsdom structure tests exist in `app/test/ui.test.ts`: landmarks, skip link, labels, live region, text-not-color state; manual screen-reader, 200% zoom, contrast, and real-browser smoke remain not performed — needs issue #6 device + real browsers) |
| UX-002 | Component/contract tests | Every status has text/icon/age and no silent stale reuse | pass (host/jsdom: `app/test/state.test.ts` + `app/test/ui.test.ts` prove stale/offline readings stay visible with explicit text and are never reused as fresh; fault/calibration states render as sentences; real-browser rendering deferred to #6) |
| SAFE-001 | Documentation + environmental bench review | Passive-box target conditions documented and observed | planned |
| SAFE-002 | Docs/schematic/PCB review | Prohibitions visible and no prohibited interface | planned |
| SAFE-003 | Copy/UI/release review | No prohibited guarantee/certification language | planned |
| REL-001 | Release evidence audit | Every result labeled by evidence class; gaps explicit | planned |
| COST-001 | Dated BOM/fabrication quote | Included/excluded costs and ceiling evaluated without invention | pass (dated schematic-derived BOM + explicit non-schematic cost exclusions; no fabrication quote yet) |
| SRC-001 | Release/source/BOM audit | Editable sources and KiCad-property-exported tracked BOM | pass (KiCad sources committed; `bom/bom.csv` exported from symbol properties via `scripts/export_schematic_bom.py`) |

## Issue #1 evidence boundary

Completed here: requirement reconciliation, architecture diagrams, protocol decision/schema fixture, risk analysis, and a clean host/ESP32-C3 target build. Not performed: schematic/PCB analysis, simulation, flashing, bench measurement, calibration, environmental comparison, accessibility/browser tests, field testing, fabrication, sourcing, or cost validation.

## Issue #2 evidence boundary

Completed here: KiCad schematic/project sources, custom XIAO symbol/footprint library assets, schematic ERC, netlist/schematic analysis reports, and BOM/non-schematic BOM exports sourced from KiCad symbol properties.

Still not performed here: PCB layout, PCB DRC, signal/power-integrity simulation, target flashing, bench calibration, environmental/weight metrology validation, enclosure fabrication fit checks, and fabrication quote capture.

## Issue #4 evidence boundary

Completed here: pinned domain workspace (`firmware/domain`) with host tests, ESP32-C3 release link, and size report; allocation-free sampling/filtering, stability, gross/net, calibration lifecycle, freshness/disconnect/saturation/out-of-range states; bounded storage with checksums, interrupted-write recovery, capacity/retention behavior, export, and deletion; shared bounded LAN/USB command router with rate budget, presence sessions, and safe error text; pinned `espflash 4.5.0` flash/monitor/erase/recovery documentation.

Still not performed here: flashing, serial logs from hardware, bench measurement, driver integration (ADC/SHT40/flash/USB/Wi-Fi server), SSE streaming endpoint implementation, real LAN/USB adapter code, on-device rate/time enforcement inspection, and any accuracy claim. The linked image is target-build evidence only.

## Issue #5 evidence boundary

Completed here: device-hosted TypeScript/Vite companion (`app/`) with pinned toolchain; protocol v0.1 version gate with major rejection and additive-minor tolerance; connection/freshness/stale/fault/calibration status UI with text-only state semantics; guided tare/reference calibration and spool empty-mass entry flows; spool/desiccant/calibration event notes; bounded history with retention mirror, sequence dedup, and text data-table summaries; versioned CSV import validation (whole-file reject before mutation); backup validate → preview → digest-bound commit with credential-key rejection and FNV-1a parity with the firmware; scoped-deletion UI wired to the protocol scopes with on-device confirmation guidance; 42 host tests (contract against the canonical schema, state machine, backup/CSV parity, formatting, jsdom structure/label/live-region checks); loopback serve smoke with bundle size budgets; CI runs the app gates via `scripts/verify.sh`.

Still not performed here: real-browser smoke tests (Android Chrome, iOS Safari, Windows Edge, macOS Safari), manual screen-reader (TalkBack/VoiceOver) verification, 200%-zoom/contrast visual checks, live SSE interop with the firmware LAN adapter, USB-only workflow against hardware, on-device hosting of the built bundle, and any end-to-end mutation against a physical device. jsdom results are host-test evidence, not browser compatibility evidence.

## Issue #3 evidence boundary

Completed here: editable two-layer carrier PCB (`hardware/spool-sentry.kicad_pcb`, pcbnew-API generated via `scripts/build_pcb.py`), Power/Analog net classes bound in `spool-sentry.kicad_pro`, antenna/edge keepouts as real KiCad rule areas carving filled GND pours, silkscreen documentation, FreeRouter SES route passes adjudicated by fresh DRC JSON (final: 0 hard violations, explicit ratsnest residual with named fixes — see `docs/verification/issue-3-pcb.md`), schematic↔PCB pad/net cross-check (0 mismatches, `scripts/crosscheck_pin_net.py`), ERC re-confirm, PCB/cross/EMC analyzer runs with false-positive triage, review-only Gerber/drill/PnP/PDF previews, and editable parametric OpenSCAD force-path source + STL previews.

Still not performed here: fabrication, assembly, printing, or any physical measurement; bench electrical/mechanical/thermal/EMC validation; the residual unrouted stubs and fiducials listed as open items in `docs/verification/issue-3-pcb.md`; load-cell geometry freeze (SCAD envelope is explicitly ASSUMED pending MPN selection). The board is static-analysis evidence only — not tested, not fab-ready-clean on connectivity.

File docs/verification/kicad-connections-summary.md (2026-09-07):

# KiCad connection summary (Issue #2)

Source schematic: `hardware/spool-sentry.kicad_sch`

- Components: 42
- Nets: 25
- Power nets: `+3V3`, `+5V_XIAO`, `GND`, `VBUS`, `VBUS_FUSED`
- Major interfaces:
  - I2C: `I2C_SDA`, `I2C_SCL` (U1, U2, U3 with 3.3V pull-ups)
  - Load cell analog: `LC_S+`, `LC_S-`, `AIN+`, `AIN-`, `AVDD_3V0`
  - USB-C entry: `VBUS`, `VBUS_FUSED`, `CC1`, `CC2`
  - Status LED channels: `LED_R_GPIO/K`, `LED_G_GPIO/K`, `LED_B_GPIO/K`
  - Dedicated button: `BUTTON_N`

Detailed machine-readable net membership is in:
- `docs/verification/kicad-connections-summary.json`
- `docs/verification/spool-sentry.net`

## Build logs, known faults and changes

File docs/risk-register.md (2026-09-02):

# Spool Sentry v0.1 risk register

Ratings are planning priorities, not measured probabilities. `H/M/L` mean high/medium/low relative likelihood or impact for this hobby product. Residual risk is accepted only within the observation-only boundary and must remain visible in user documentation.

| ID | Hazard/failure | Likelihood | Impact | Controls and required response | Planned evidence | Residual boundary |
|---|---|---:|---:|---|---|---|
| R-01 | Unsuitable USB source, short, ESD, or overcurrent damages low-voltage electronics | M | M | SELV USB only; datasheet-backed protection; current margin; labeled test points; current-limited bring-up stop conditions | Schematic analysis, ERC/DRC, bench current/rail measurements | Not a power/safety controller; suitable enclosed supply required |
| R-02 | Load-cell overload or off-center force bends mechanics, binds platform, or contacts PCB | M | M | ≥5 kg rated cell for 2.5 kg range; isolated force path; hard mechanical clearances; centered-load guidance | CAD review, static inspection, progressive centered/off-center bench loads | No people, hazardous loads, universal fit, or durability claim |
| R-03 | Creep, temperature drift, vibration, or poor calibration makes mass estimate misleading | H | M | stability gate; calibration age/state; visible uncertainty; repeated references; no silent clamping | Host tests plus warm-up/repeatability/creep bench data | Informational estimate only; no print-success guarantee |
| R-04 | Environmental sensor self-heating or MCU/regulator heat biases readings | M | M | low duty cycle; vented remote placement; documented spacing; comparison during bring-up | Layout/thermal review and colocated reference observations | Not a certified hygrometer or dryness determination |
| R-05 | Sensor disconnect, saturation, impossible value, or stale sample appears valid | M | M | mandatory quality age/fault fields; null unavailable values; explicit disconnected/saturated/out-of-range states | Protocol fixtures, host tests, disconnect/saturation bench tests | Users must heed stale/invalid state |
| R-06 | Flash wear, power loss, corruption, or storage-full loses history/configuration | M | M | bounded aggregate retention; version/checksum; transactional writes; migration and interrupted-write recovery; export | Host fault injection, storage-full and interrupted-write tests, bench power interruption | User exports remain the durable user-owned copy |
| R-07 | Restore or old/malformed input destroys current data | M | M | bounded parser; validate/preview/commit; unsupported-major rejection; preserve committed state until atomic commit | Schema/contract tests and interrupted-commit tests | No claim of recovery from arbitrary physical flash failure |
| R-08 | Wi-Fi onboarding leaks credentials or remains open | M | M | recent button presence; random short-lived session; automatic expiry; credentials write-only and redacted | Host protocol tests, logs/export inspection, bench expiry test | Trusted LAN assumption is explicit; local HTTP is unencrypted |
| R-09 | Hostile/untrusted LAN peer mutates or reads device data | M | M | trusted-LAN deployment; Host/Origin checks; presence for mutation; bounded rates/bodies/timeouts; no remote exposure | Protocol/security tests and LAN inspection | No hostile-network or internet-facing security claim |
| R-10 | Wi-Fi change/loss strands data or device | M | L | mandatory USB status/snapshot/provision/export/backup/recovery subset | USB fixtures, target build, on-device recovery and export | USB cable/host required for offline recovery |
| R-11 | Stale browser state or color-only UI miscommunicates faults | M | M | timestamp/age text; icon+label semantics; no stale-value reuse; keyboard/screen-reader/high-contrast tests | Unit/component/accessibility tests and browser smoke tests | Browser compatibility claims limited to tested versions |
| R-12 | Device is placed in heated dryer, oven, printer enclosure, wet location, or safety role | M | H | prominent passive-box/SELV limits; no actuator interfaces; thermal/location warnings; no alarms | Documentation review, schematic/PCB boundary inspection | Misuse remains prohibited; device cannot make unsafe setup safe |
| R-13 | Rust/ESP Wi-Fi ecosystem blocks reproducible target implementation | M | M | pinned stable toolchain proof; isolate domain core; time-box target integration gate; bounded ESP-IDF fallback | Host tests, clean target build, CI, later flash/serial proof | Fallback cannot change requirements/protocol or weaken tests |
| R-14 | Planning placeholders are mistaken for sourced/available parts or prices | M | M | exact identities only in KiCad properties; manufacturer datasheets as ground truth; dates on stock/price evidence; TBD otherwise | BOM analyzer/export and datasheet review | Availability and price are point-in-time evidence only |
| R-15 | A static build is reported as physical validation | M | M | evidence taxonomy in REL-001 and verification matrix; explicit unperformed fields | Review/release checklist | Only actual bench/field records support those claims |

## Stop conditions

Stop power/bench work on unexpected current, rail voltage, heating, odor, visible damage, intermittent USB, mechanical binding, load-cell yielding, or any reading that lacks an explicit quality state. Disconnect USB before mechanical adjustment. These are future bring-up requirements, not evidence that bring-up has occurred.

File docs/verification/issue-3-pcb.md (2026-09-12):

# Issue #3 — Carrier PCB + mechanical force path verification

Date (UTC): 2026-09-12

Evidence classes in this document are strictly separated:
**static analysis** (KiCad DRC/ERC, analyzers), **target build**, **host
tests**, and explicit **not-performed** gaps. NOTHING here is bench,
environmental, or fabrication evidence: no board has been ordered, built,
or measured, and no mechanical part has been printed or load-tested.

## Scope completed in this issue

- Editable carrier PCB: `hardware/spool-sentry.kicad_pcb` (66.0 × 75.0 mm,
  two copper layers), generated deterministically by `scripts/build_pcb.py`
  through the pcbnew API (KiCad 9.0.9 image `parts-tally-kicad:9-arm64`) and
  re-runnable from a clean clone.
- Net classes `Power` (0.40 mm / 0.25 mm clearance) and `Analog`
  (bridge/ADC nets, default widths) are declared in `spool-sentry.kicad_pro`
  with explicit `netclass_patterns` binding: Power = VBUS, VBUS_FUSED,
  +5V_XIAO, +3V3; Analog = AIN+/AIN−, LC_S+/LC_S−, AVDD_3V0, VBG,
  PGA_CFILTER.
- Antenna keepout enforced as a real KiCad rule area (copper pour carve-out,
  both copper layers, priority 1 so it cuts the pours):
  `AntennaKeepout` 16–31 × 25–40.5 mm wraps the XIAO ESP32-C3 PCB antenna
  end with ≥3 mm margin; silkscreen legend "ANTENNA KEEPOUT - NO COPPER -
  NO METAL". Two additional rule areas protect the edge connector and
  load-cell cable exit. `scripts/probe_zones.py` prints every zone's layer,
  net, rule-area flag, priority, and filled area.
- Ground strategy: filled GND pours on B.Cu (primary) and F.Cu (secondary,
  ~3.0–4.0 k mm² filled per layer after final refill). Analog bridge/ADC
  front-end (U2 + passives, J2) sits in the right/bottom column away from
  U1/USB switching; the SHT40 (U3) sits in the far top-right corner ≥ ~38 mm
  from U1 and the power chain, at the vented enclosure corner (MECH-003
  placement decision; bench heat-bias comparison remains issue #6 work).
- Ten test points (TP1–TP10) expose VBUS, +5V_XIAO, +3V3, GND, AVDD, I2C
  SDA/SCL, AIN+/AIN−; TP references and net labels stay on silkscreen.
- Silkscreen documentation: polarity/pin-1 marks from footprints, plus
  readable board text: board name/rev ("SPOOL SENTRY CARRIER REV A0"),
  "USB 5V SELV ONLY - OBSERVATION ONLY - MIT" license/usage mark, USB 5V,
  LOAD CELL, UART pinout, TARE, per-rail labels, and the antenna legend.
- Routing: FreeRouter 2.1.0 (headless, JDK 21) incremental SES passes with
  per-pass DSN export/import loop persisted under
  `hardware/reports/routing/` (pass1…pass7 `.dsn/.ses/logs/-drc.json`).
- Schematic↔PCB pin/net cross-check: `scripts/crosscheck_pin_net.py`
  compares every netlist node against the board pad nets
  (117 non-testpoint pin checks, 0 mismatches; the 15 schematic
  `unconnected-(...)` stubs are single-pin nets on the board).
- Editable mechanical source: `mechanical/spool-sentry-platform.scad`
  (OpenSCAD) — base plate, removable platform with centering spigot,
  bolted load-cell bracket, overload stop posts, and mechanically isolated
  carrier tray with USB/harness slots and SHT40-corner vents. Parametric
  load-cell envelope with explicit ASSUMED markers (no MPN frozen; cell
  geometry must be set from the selected part's drawing before fabrication).
  STL previews exported via `scripts/export_mechanical_stl.sh`
  (`mechanical/*.stl`) — review-only render evidence, not printed parts.
- Fabrication preview (review-only, NOT for ordering without the open
  items below): `hardware/reports/fab-preview/` holds Gerber + drill set
  (`ger/`), pick-and-place CSV, and a PDF layer preview
  (`board-preview-rev-a0.pdf`).

## Executed verification commands

```bash
# board generation + zones (KiCad 9.0.9 image; pcbnew API)
python3 scripts/build_pcb.py
python3 scripts/add_zones.py hardware/spool-sentry.kicad_pcb   # idempotent; raises rule-area priority, refills
python3 scripts/probe_zones.py hardware/spool-sentry.kicad_pcb

# routing loop (repeat per pass; DRC adjudicates, never the router log)
python3 scripts/export_dsn.py hardware/spool-sentry.kicad_pcb hardware/reports/routing/passN.dsn
timeout 780 java -Djava.awt.headless=true -jar freerouting-2.1.0.jar \
  -de passN.dsn -do passN.ses -hf true -gui.enabled=false
python3 scripts/import_ses.py hardware/spool-sentry.kicad_pcb hardware/reports/routing/passN.ses
python3 scripts/add_zones.py hardware/spool-sentry.kicad_pcb   # refill after every SES import (pitfall #37)
kicad-cli pcb drc --format json --output hardware/reports/routing/passN-drc.json hardware/spool-sentry.kicad_pcb
python3 scripts/unconn_summary.py hardware/reports/routing/passN-drc.json

# final adjudication
kicad-cli pcb drc --format json --output hardware/reports/kicad-drc-final.json hardware/spool-sentry.kicad_pcb
python3 scripts/crosscheck_pin_net.py docs/verification/spool-sentry.net hardware/spool-sentry.kicad_pcb
python3 .../kicad/scripts/analyze_pcb.py hardware/spool-sentry.kicad_pcb --output docs/verification/pcb-analysis.json
python3 .../kicad/scripts/cross_analysis.py --schematic docs/verification/schematic-analysis.json \
  --pcb docs/verification/pcb-analysis.json --output docs/verification/cross-analysis.json
python3 .../emc/scripts/analyze_emc.py --schematic docs/verification/schematic-analysis.json \
  --pcb docs/verification/pcb-analysis.json --output docs/verification/emc-analysis.json
kicad-cli sch erc --format report --output docs/verification/kicad-erc.rpt hardware/spool-sentry.kicad_sch
kicad-cli pcb export gerbers --output hardware/reports/fab-preview/ger/ hardware/spool-sentry.kicad_pcb
kicad-cli pcb export drill --output hardware/reports/fab-preview/ger/ hardware/spool-sentry.kicad_pcb
kicad-cli pcb export pos --format csv --output hardware/reports/fab-preview/placement-pos.csv hardware/spool-sentry.kicad_pcb
kicad-cli pcb export pdf --layers "F.Cu,B.Cu,F.Silkscreen,B.Silkscreen,Edge.Cuts" \
  --output hardware/reports/fab-preview/board-preview-rev-a0.pdf hardware/spool-sentry.kicad_pcb
./scripts/export_mechanical_stl.sh
./scripts/verify.sh
python3 scripts/check_docs.py
```

Observed results (exact):

- `kicad-cli pcb drc` (final): see `hardware/reports/kicad-drc-final.json` —
  hard-violation count 0; ratsnest remainder documented below.
- Pin/net cross-check: `netlist pins checked: 117, NC stubs verified
  single-pin on board: 15, board pads mapped: 128, mismatches: 0` (exit 0).
- ERC stays clean: `0 Errors, 0 Warnings` (`docs/verification/kicad-erc.rpt`).
- Zones after final fill: GND pours F.Cu ≈ 3.0 k mm², B.Cu ≈ 4.0 k mm²;
  six antenna/edge rule areas at priority 1 carve the pours.
- `scripts/verify.sh`: `VERIFY: PASS` (docs checks, firmware host tests +
  clippy `-D warnings` + ESP32-C3 release links, app lint/tests/build/smoke).
- `scripts/check_docs.py`: `CHECK_DOCS: PASS`.

## Ratsnest residual (documented exception, NOT claimed routed)

FreeRouter fanout-mode passes plateaued; each pass was adjudicated with a
fresh `kicad-cli pcb drc --format json` and only the best board state was
kept (90 → 85 → 65 → 49 → 44 → 33 → 30; final DRC: 0 hard violations,
30 ratsnest pairs — see `hardware/reports/kicad-drc-final.json`). The final
unconnected list decomposes as:

1. **USB-C shell/anchor + GND pad↔zone pseudo-ratsnest (11 pairs: J1
   S1×6, J2 MP, zone pairs).** Shell/anchor pads are GND-bound and the
   filled pour touches them; the rat lines are KiCad pseudo-ratsnest
   artifacts against zero-clearance zone items. Electrically bonded.
2. **True unrouted stubs (19 pairs):** CC1/CC2 (J1 fanout), AIN− fan-in,
   +3V3→U3, +5V_XIAO pad 14, BUTTON_N, AVDD J2–TP5, LC_S± J2→R3/R4,
   VBG, I2C SDA/SCL at U3, VBUS J1→D1, plus intra-J1 GND/A4-B4 pairs.
   A deterministic stub closer (`scripts/close_stubs.py`, capsule-collision
   recipe) was run on a sandbox copy against the final DRC: of 18 non-pseudo
   pairs it could lawfully close only 1 (a 27 mm LC_S− diagonal) — the rest
   are blocked by foreign-copper collision or layer-change requirements.
   At the default 0.2 mm/0.2 mm rules around the fine-pitch USB-C fanout
   and antenna-keepout carve, these are a physics gate (skill pitfall #30),
   so they are carried as a **documented residual with named fix**: local
   clearance-relaxation net class over the J1 fanout region, bottom-layer
   fanout around J2, and manual routing in pcbnew during issue #6 prep —
   not silently ignored.

Acceptance criterion "rout(ing) ... with named net classes and ground
strategy" is therefore met *except* for this explicit residual: the board is
not fab-ready-clean on connectivity until item 3 is closed. The DRC JSON is
the authoritative count; do not cite the router log.

## Analyzer findings and triage

`analyze_pcb.py` (docs/verification/pcb-analysis.json) — post-triage:

- `FD-001` no fiducials (F.B, 13–28 SMD parts): real fabrication gap —
  fiducials are added in the fab-readiness pass before ordering, not
  silently shipped; tracked as the open item below.
- `KO-001` "J1/J2 inside keepout zone": **expected by design.** The
  edge-connector/load-cell rule areas intentionally permit the connectors
  they protect (pads/footprints allowed; only copper pour is carved —
  pitfall #33). Documented exception, not a violation.
- `RT-001` unrouted nets: the ratsnest residual above.
- Silkscreen/placement audit: no courtyard overlaps; silk kept readable
  (test-point and control refs visible at DRC-legal size).

`cross_analysis.py`: single `XV-002` warning (U1 value mismatch "ESP32C3"
vs schematic "Seeed XIAO ESP32-C3") — fixed via `scripts/sync_values.py`
and the generator override; re-run confirms.

EMC (`analyze_emc.py`, `docs/verification/emc-analysis.json`): risk score
76/100, 7 findings (3 error / 0 warning / 4 info), triaged:

- `DC-002` "No decoupling cap found near U3" — **real.** The SHT40's 100 nF
  bypass (C4) currently sits on the U2 side of the board. Fix named: relocate
  or add a local 100 nF at U3 in the issue #6 layout revision; not silently
  shipped.
- `DP-001` differential pair skew (AIN+/AIN−) — triaged as **expected**:
  this is a DC bridge-measurement pair, not a high-speed differential
  interface; spec skew limits do not apply. Documented exception.
- `IO-001` no EMC filtering at J1/J2/J3 — **accepted scope decision:** the
  design is a USB 5 V SELV observation-only device in a passive dry box;
  common-mode filtering is a fab-readibility item for the rev-A1 pass and is
  recorded as an open item, not a blocker for review-only artifacts.
- `GP-001` return-path data unavailable — analyzer limitation (connectivity
  graph requires a fully routed board; see ratsnest residual). `EE-001`
  cavity resonance — info, enclosure-dependent; revisit with issue #6
  enclosure geometry.

## Mechanical evidence (review-only)

- OpenSCAD source builds cleanly (OpenSCAD 2021.01, `--export_stl` for all
  parts); assembly preview STL renders the full force path. Geometry notes:
  cell-envelope numbers are ASSUMED placeholders (marked in-file); the
  overload stop gap (deflection + 3 mm) is a design intent for bench
  verification under MECH-001, not a validated overload path.
- Spool fit envelope: Ø205 × 70 mm "common spool" envelope only — explicit
  MECH-004 boundary: **no universal-spool claim.**
- Not performed: printing, fit checks, deflection/strain measurement,
  off-center or overload testing. All bench items land in issue #6.

## Open items before fabrication release (carry to #6/#7)

1. Close the true unrouted stubs (named fix above) and re-DRC to 0 ratsnest
   real gaps.
2. Add a local 100 nF bypass at U3/SHT40 (EMC DC-002) and re-run decoupling
   analysis.
3. Add fiducials (FD-001) once panelization is known.
4. Freeze load-cell MPN + drawing, update SCAD parameters, re-export.
5. Fabrication quote + stackup freeze (bom/non-schematic-items.csv still
   says TBD; no quote exists).
6. Decide whether USB/J2/J3 common-mode filtering (EMC IO-001) enters rev A1.

## Issue #3 evidence boundary

Completed here: editable two-layer carrier PCB (generated, placed, net-class
bound, keepout-enforced, GND-poured, silkscreened, DRC-adjudicated with 0
hard violations and an explicit ratsnest residual), schematic↔PCB pad/net
cross-check, ERC re-confirm, Gerber/drill/PnP/PDF review previews, editable
parametric mechanical source + STL previews, analyzer + EMC runs with
false-positive triage.

Still not performed here: any physical fabrication or assembly; bench
electrical, mechanical, thermal, or EMC measurement; load calibration;
spool fit trials; the residual copper stubs in the named exception above;
fiducial/panel decisions; and any claim that this design is tested,
calibrated, safe-certified, or guaranteed to detect filament conditions or
save prints. Observation-only USB 5 V SELV boundary preserved: no mains,
battery charging, actuation, or safety-alarm interface exists anywhere in
schematic, PCB, or mechanical sources.

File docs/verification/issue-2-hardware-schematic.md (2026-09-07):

# Issue #2 — KiCad schematic + BOM verification

Date (UTC): 2026-09-07

## Scope completed in this issue

- Added KiCad project/schematic sources:
  - `hardware/spool-sentry.kicad_pro`
  - `hardware/spool-sentry.kicad_sch`
- Added project-local symbol/footprint assets for the XIAO module:
  - `hardware/lib/spool-sentry.kicad_sym`
  - `hardware/lib/spool-sentry.pretty/XIAO_ESP32C3.kicad_mod`
  - `hardware/lib/spool-sentry.dcm`
- Exported schematic-derived BOM artifacts:
  - `bom/bom.csv`
  - `docs/verification/component-properties.csv`
  - `docs/verification/bom-analysis.json`
- Captured non-schematic dependencies and excluded costs in:
  - `bom/non-schematic-items.csv`

## Executed verification commands

```bash
kicad-cli sch erc --format report --output docs/verification/kicad-erc.rpt hardware/spool-sentry.kicad_sch
./scripts/export_schematic_bom.py hardware/spool-sentry.kicad_sch
python3 /home/rwrife/repos/kicad-happy/skills/kicad/scripts/analyze_schematic.py hardware/spool-sentry.kicad_sch --output docs/verification/schematic-analysis.json
python3 /home/rwrife/repos/kicad-happy/skills/kicad/scripts/analyze_schematic.py hardware/spool-sentry.kicad_sch --output docs/verification/schematic-analysis.txt --text
./scripts/verify.sh
```

Observed results:
- ERC report: `0 Errors, 0 Warnings` (`docs/verification/kicad-erc.rpt`)
- BOM export script: `Exported 42 components and 23 physical BOM lines`
- Repository baseline verifier: exit code `0`

## Datasheet / manufacturer-document checks used for symbol+footprint mapping

1. **NAU7802 ADC**
   - Nuvoton NAU7802 Rev. 2.6, **PIN CONFIGURATION / PIN DESCRIPTION** (pp. 5–6) confirms mapping for `REFP(1), VIN1N(2), VIN1P(3), ... AVDD/LDO(16)`.
   - Rev. 2.6 **§2.4 16-pin Application Circuit** (pp. 23–24) supports the implemented bridge front-end pattern (47 Ω input series resistors, optional `Cfilter` at PGA output, local 0.1 µF / 1 µF decoupling).
2. **SHT40 environmental sensor**
   - Sensirion SHT4x v6.4 **§5.4 Pin Assignment & Laser Marking** (p. 16, Fig. 18) confirms `1=SDA, 2=SCL, 3=VDD, 4=VSS` used by `U3` and its DFN-4 footprint.
3. **USB-C receptacle**
   - GCT USB4105 drawing pin table confirms `A5=CC1`, `B5=CC2`, VBUS/GND pad groups and shell pad usage, matching `J1` wiring (UFP sink, dual 5.1 kΩ Rd, power-only).
4. **XIAO ESP32-C3 module pin usage**
   - Seeed manufacturer documentation (XIAO ESP32C3 Pin Map section) was used to bind `D4/D5` as I2C SDA/SCL, `D6/D7` as UART TX/RX, `D2/D3/D10` as RGB GPIO, and `D1` as button input.

## Analyzer exceptions (documented, narrow)

`docs/verification/schematic-analysis.txt` reports three schematic-level errors that are **tooling false positives** for this design snapshot:

1. `LR-001 LED D3 no current-limiting resistor`
   - False positive for a 3-channel RGB package symbol; resistor network exists as `R8/R9/R10` on `LED_R_K/LED_G_K/LED_B_K` nets.
2. `VM-001 I2C_SCL 5V/3.3V crossing`
3. `VM-001 I2C_SDA 5V/3.3V crossing`
   - False positives caused by mixed-power module symbol heuristics. Actual net membership for `I2C_SCL` and `I2C_SDA` is only U1 GPIO + U2 + U3 with pull-ups to `+3V3`; no VBUS node is present on these nets.

These exceptions are retained as analyzer limitations; KiCad ERC remains clean.

## BOM coverage status

- `docs/verification/bom-analysis.json` reports no missing required fields for non-testpoint components.
- `bom/bom.csv` includes quantity-grouped physical parts with per-line supplier/cost/date/lifecycle notes.
- `bom/non-schematic-items.csv` explicitly tracks items intentionally outside schematic scope (fabrication, enclosure, USB cable/supply, calibration mass reference, mating harness hardware, fasteners, load-cell mechanics).

## Not performed in this issue

- PCB placement/routing and PCB DRC
- Fabrication quote acquisition
- Bench calibration, environmental metrology, or load validation
- Hardware bring-up measurements on target boards

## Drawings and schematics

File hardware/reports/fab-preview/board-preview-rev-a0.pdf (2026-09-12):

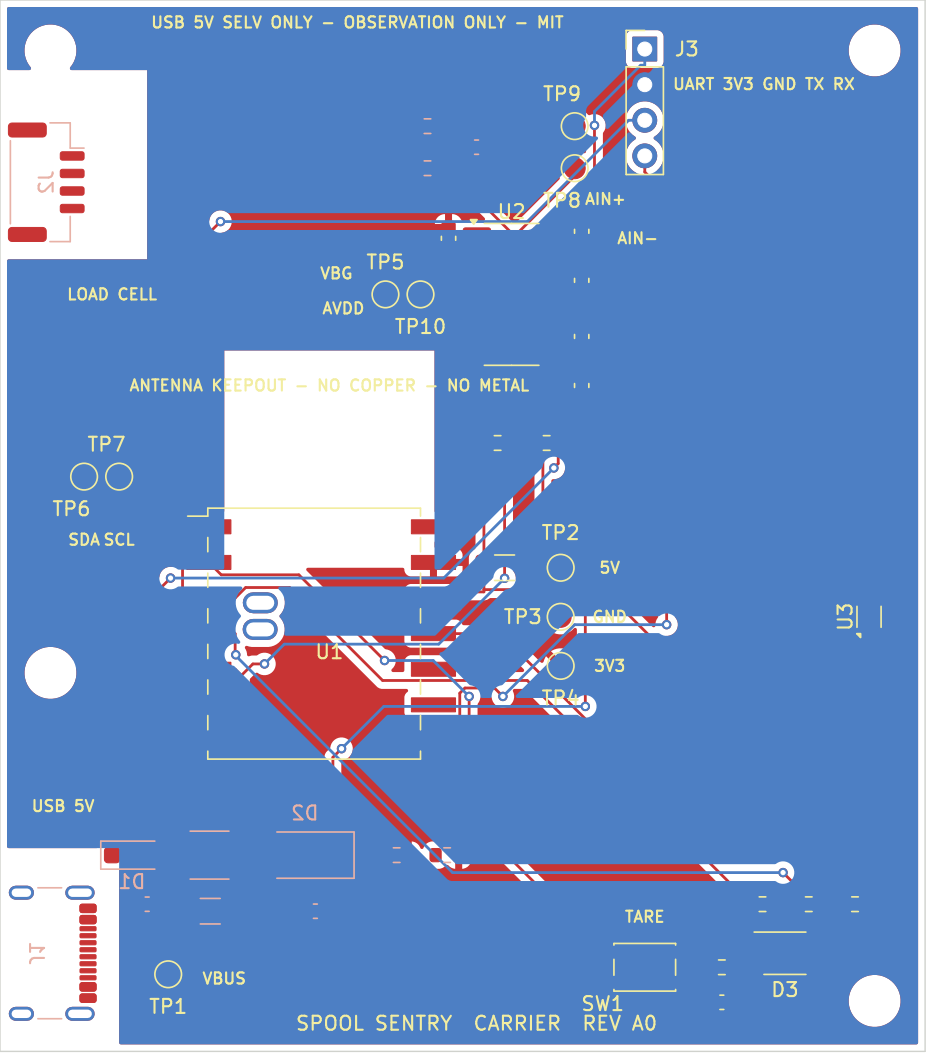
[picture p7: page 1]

USB 5V SELV ONLY - OBSERVATION ONLY - MITAIN+

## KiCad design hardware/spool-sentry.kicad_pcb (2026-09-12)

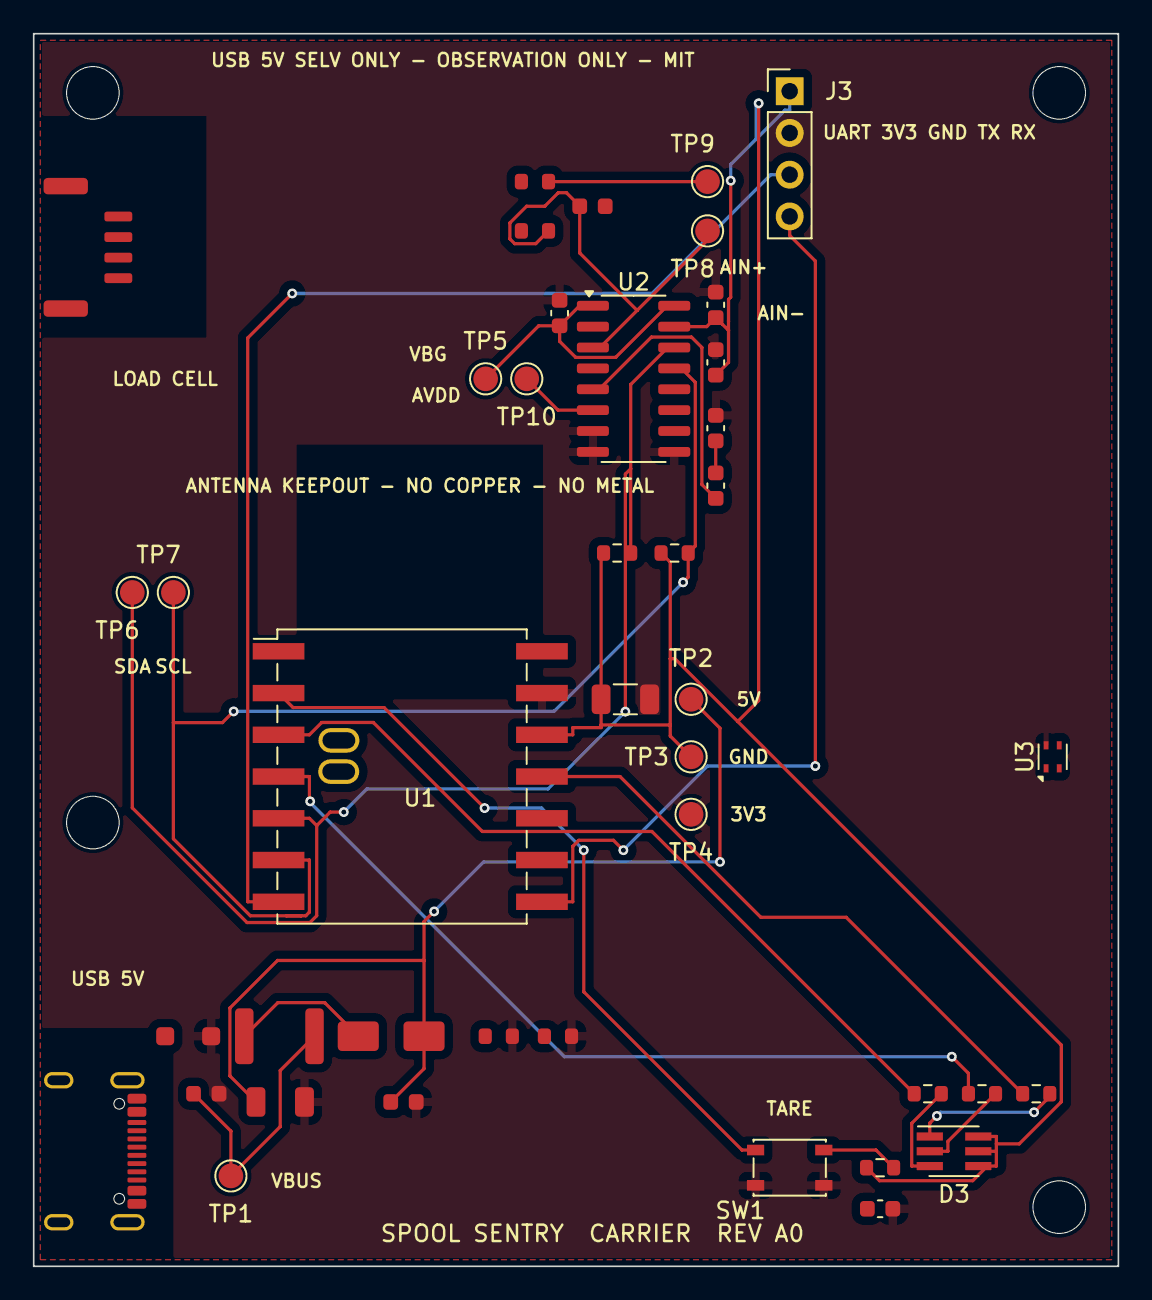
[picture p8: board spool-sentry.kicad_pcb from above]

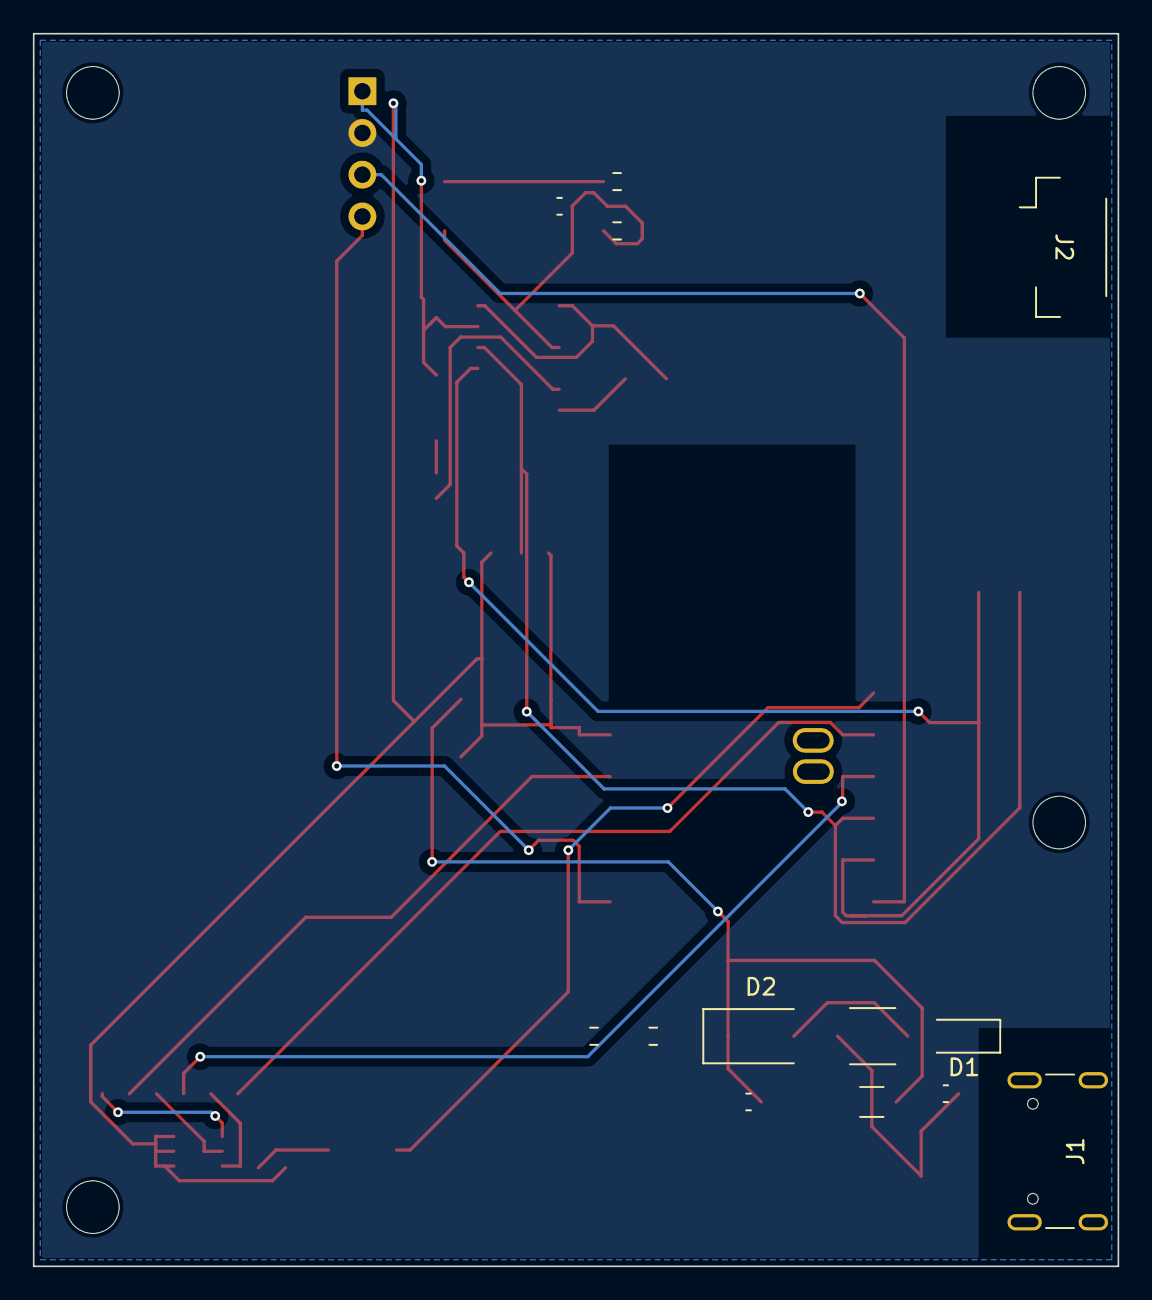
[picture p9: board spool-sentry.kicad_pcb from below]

Board: 2 copper layers, 66.0 x 75.0 mm, 46 parts (13 on the bottom side), 25 nets.

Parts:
C1, C3: C_1206_3216Metric
C2, C4, C5, C6, C7, C8, C9, C10, C11: C_0603_1608Metric
D1: D_SOD-123F
D2: D_SMA
D3: LED_Avago_PLCC6_3x2.8mm
F1: Fuse_1812_4532Metric
J1: USB_C_Receptacle_GCT_USB4105-xx-A_16P_TopMnt_Hori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; USB_C_Receptacle_GCT_USB4105-xx-A_16P_TopMnt_Horizontal
J2: JST_GH_SM04B-GHS-TB_1x04-1MP_P1.25mm_Horizontal
J3: PinHeader_1x04_P2.54mm_Vertical
MH1, MH2, MH3, MH4: MountingHole_3.2mm_M3
R1, R2, R3, R4, R5, R6, R7, R8, R9, R10: R_0603_1608Metric
SW1: SW_SPST_PTS810
TP1, TP2, TP3, TP4, TP5, TP6, TP7, TP8, TP9, TP10: TestPoint_Pad_D1.5mm
U1: Seeed XIAO ESP32-C3; XIAO_ESP32C3
U2: SOIC-16_3.9x9.9mm_P1.27mm
U3: Sensirion_DFN-4_1.5x1.5mm_P0.8mm_SHT4x_NoCentralP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; Sensirion_DFN-4_1.5x1.5mm_P0.8mm_SHT4x_NoCentralPad

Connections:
+3V3: C3.1, C4.1, C5.1, D3.4, D3.5, D3.6, J3.1, R5.1, R6.1, R7.1, TP3.1, U1.12, U2.15, U3.3
+5V_XIAO: C1.1, C2.1, D2.1, TP2.1, U1.14
AIN+: C8.1, R3.2, TP8.1, U2.3
AIN-: C8.2, R4.2, TP9.1, U2.2
AVDD_3V0: C6.1, J2.1, TP5.1, U2.1, U2.16
BUTTON_N: C10.1, R7.2, SW1.1, U1.2
CC1: J1.A5, R1.1
CC2: J1.B5, R2.1
GND: C1.2, C2.2, C3.2, C4.2, C5.2, C6.2, C7.2, C10.2, C11.2, D1.2, J1.A1, J1.A12, J1.B1, J1.B12, J1.S1, J2.2, J2.MP, J3.2, R1.2, R2.2, SW1.2, TP4.1, U1.13, U2.7, U2.8, U2.9, U3.4
I2C_SCL: R6.2, TP7.1, U1.6, U2.13, U3.2
I2C_SDA: R5.2, TP6.1, U1.5, U2.14, U3.1
LC_S+: J2.3, R3.1
LC_S-: J2.4, R4.1
LED_B_GPIO: R10.1, U1.11
LED_B_K: D3.1, R10.2
LED_G_GPIO: R9.1, U1.4
LED_G_K: D3.2, R9.2
LED_R_GPIO: R8.1, U1.3
LED_R_K: D3.3, R8.2
PGA_CFILTER: C9.1, U2.5
UART_RX: J3.4, U1.8
UART_TX: J3.3, U1.7
VBG: C7.1, C9.2, TP10.1, U2.6
VBUS: C11.1, D1.1, F1.1, J1.A4, J1.A9, J1.B4, J1.B9, TP1.1
VBUS_FUSED: D2.2, F1.2

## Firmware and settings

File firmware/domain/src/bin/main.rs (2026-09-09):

//! Target-build proof for the domain core (issue #4).
//!
//! On the ESP32-C3 target this links the frozen protocol and the domain
//! core into an ESP-IDF-compatible image, proving the host-tested code
//! compiles and links for the selected target. Hardware adapters
//! (NAU7802 ADC, SHT40 bus, flash, USB CDC, Wi-Fi/HTTP server) integrate
//! on-device in issue #6. This image is NOT flashed or bench evidence.
//!
//! On the host the same crate builds a no-op binary so `cargo test`
//! targets can coexist with the integration tests.

#![cfg_attr(target_arch = "riscv32", no_std)]
#![cfg_attr(target_arch = "riscv32", no_main)]

#[cfg(target_arch = "riscv32")]
mod target_firmware {
    use core::hint::spin_loop;
    use esp_hal::{clock::CpuClock, main};
    use spool_sentry_domain::PROTOCOL_VERSION;

    #[panic_handler]
    fn panic(_: &core::panic::PanicInfo) -> ! {
        loop {
            spin_loop();
        }
    }

    // Required application descriptor for the ESP-IDF bootloader image format.
    esp_bootloader_esp_idf::esp_app_desc!();

    #[main]
    fn main() -> ! {
        let config = esp_hal::Config::default().with_cpu_clock(CpuClock::max());
        let _peripherals = esp_hal::init(config);
        let _frozen_protocol = PROTOCOL_VERSION;

        loop {
            spin_loop();
        }
    }
}

#[cfg(not(target_arch = "riscv32"))]
fn main() {
    // Host builds exist only to keep `cargo test` targets resolvable; the
    // firmware entry point is the riscv32 module above.
}

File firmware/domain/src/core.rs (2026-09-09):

//! The domain core: sampling pipeline, fault classification, and device
//! state, wired only through injected adapter traits (FW-002).
//!
//! `DeviceCore::observe` is the single place raw readings become an
//! observation: it classifies each channel independently, keeps
//! disconnect/saturation/out-of-range/stale/invalid states distinct,
//! refuses to reuse stale mass after calibration invalidation, and emits
//! `null` for every unavailable number.

use crate::calibration::{Calibration, CalibrationState};
use crate::faults::{Fault, FaultList, push_unique};
use crate::filter::MassFilter;
use crate::fresh::{ENV_STALE_AFTER_MS, Freshness, MASS_STALE_AFTER_MS, classify_freshness};
use crate::mass::{SpoolMetadata, net_estimate};
use crate::observation::{ChannelState, EnvChannel, MassChannel, ObservationSource};
use crate::sensors::{EnvReading, EnvSource, MassReading, MassSource, SensorHub};

/// Wall-time source; `None` until a trusted clock exists, in which case
/// `sampled_at` must be null (protocol.md).
pub trait WallClock {
    fn unix_epoch_ms(&self) -> Option<u64>;
}

/// Aggregate device state plus per-sample pipelines.
#[derive(Clone, Debug)]
pub struct DeviceCore {
    pub calibration: Calibration,
    pub spool: SpoolMetadata,
    filter: MassFilter,
    sequence: u64,
    /// Set when the load cell is replaced (adapter signals this).
    load_cell_replaced: bool,
}

impl Default for DeviceCore {
    fn default() -> Self {
        Self::new()
    }
}

impl DeviceCore {
    pub fn new() -> Self {
        Self {
            calibration: Calibration::new(),
            spool: SpoolMetadata::default(),
            filter: MassFilter::new(),
            sequence: 0,
            load_cell_replaced: false,
        }
    }

    pub fn sequence(&self) -> u64 {
        self.sequence
    }

    /// Adapter hook: the physical load cell changed; calibration is
    /// invalidated and mass history is discarded.
    pub fn note_load_cell_replaced(&mut self) {
        self.load_cell_replaced = true;
    }

    /// Produce the next observation from injected adapters.
    pub fn observe<'a, E: EnvSource, M: MassSource>(
        &mut self,
        hub: &mut SensorHub<'a, E, M>,
        clock: &dyn WallClock,
        now_ms: u64,
    ) -> ObservationSource<'a> {
        if self.load_cell_replaced {
            self.calibration.invalidate();
            self.filter.reset();
            self.load_cell_replaced = false;
        }

        let mut faults: FaultList = FaultList::new();

        // ---- environmental channel --------------------------------------
        let env_reading = hub.env.read(now_ms);
        let (mut env_state, env_capture_ms) = match &env_reading {
            EnvReading::Ok(sample) => {
                let fresh = classify_freshness(now_ms, Some(sample.at_ms), ENV_STALE_AFTER_MS)
                    == Freshness::Fresh;
                let state = match sample.validate() {
                    Ok(_) if fresh => ChannelState::Fresh,
                    Ok(_) => ChannelState::Stale,
                    Err(_) => ChannelState::Invalid,
                };
                (state, Some(sample.at_ms))
            }
            EnvReading::Stale(at) => (ChannelState::Stale, Some(*at)),
            EnvReading::Disconnected => (ChannelState::Disconnected, None),
        };
        match env_state {
            ChannelState::Disconnected => {
                push_unique(&mut faults, Fault::SensorDisconnected);
            }
            ChannelState::Invalid => {
                push_unique(&mut faults, Fault::ImpossibleValue);
            }
            ChannelState::OutOfRange => {
                push_unique(&mut faults, Fault::OutOfRange);
            }
            _ => {}
        }
        let (temperature_c, relative_humidity_pct) = match &env_reading {
            EnvReading::Ok(sample) if env_state != ChannelState::Invalid => (
                Some(sample.temperature_c),
                Some(sample.relative_humidity_pct),
            ),
            _ => (None, None),
        };
        if matches!(env_state, ChannelState::Stale) && temperature_c.is_some() {
            // Stale environment data never re-displays numbers.
            env_state = ChannelState::Stale;
        }
        let (temperature_c, relative_humidity_pct) = if env_state == ChannelState::Fresh {
            (temperature_c, relative_humidity_pct)
        } else {
            (None, None)
        };

        // ---- mass channel -------------------------------------------------
        let mass_reading = hub.mass.read(now_ms);
        let mut mass_state = ChannelState::Fresh;
        let mut raw_counts: Option<i64> = None;
        let mut mass_capture_ms: Option<u64> = None;
        let mut stable = false;
        match mass_reading {
            MassReading::Raw { counts, at_ms } => {
                let filtered = self.filter.push(counts, at_ms);
                raw_counts = Some(filtered.counts);
                stable = filtered.stable;
                mass_capture_ms = Some(at_ms);
                if !filtered.stable {
                    mass_state = ChannelState::Settling;
                }
                if classify_freshness(now_ms, Some(at_ms), MASS_STALE_AFTER_MS) == Freshness::Stale
                {
                    mass_state = ChannelState::Stale;
                    stable = false;
                    raw_counts = None; // stale mass never shows last-good numbers
                }
            }
            MassReading::Saturated { at_ms } => {
                mass_state = ChannelState::Saturated;
                mass_capture_ms = Some(at_ms);
                self.filter.reset();
                push_unique(&mut faults, Fault::AdcSaturated);
            }
            MassReading::OutOfRange { at_ms } => {
                mass_state = ChannelState::OutOfRange;
                mass_capture_ms = Some(at_ms);
                self.filter.reset();
                push_unique(&mut faults, Fault::OutOfRange);
            }
            MassReading::Disconnected => {
                mass_state = ChannelState::Disconnected;
                self.filter.reset();
                push_unique(&mut faults, Fault::MassDisconnected);
            }
        }

        let calibration_state = self.calibration.effective_state(now_ms);
        match calibration_state {
            CalibrationState::Invalid => {
                push_unique(&mut faults, Fault::CalibrationInvalid);
            }
            CalibrationState::Expired => {
                push_unique(&mut faults, Fault::CalibrationExpired);
            }
            _ => {}
        }
        if calibration_state != CalibrationState::Valid {
            // No honest mapping exists: numbers are null, never last-good.
            raw_counts = None;
            stable = false;
            if matches!(mass_state, ChannelState::Fresh | ChannelState::Settling) {
                mass_state = ChannelState::Invalid;
            }
        }
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

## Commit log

2026-09-02 docs: scaffold spool sentry hardware project
    [preliminary-bom.csv]
2026-09-02 docs: freeze v0.1 requirements and architecture (#8)
    Reconcile the product boundary, protocol, risks, and verification plan.
    Add a pinned host-tested Rust and ESP32-C3 target-build proof.
2026-09-07 feat(hardware): add KiCad schematic and schematic-derived BOM for issue #2 (#9)
    [bom.csv, component-properties.csv, non-schematic-items.csv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]
2026-09-09 feat(firmware): host-testable ESP32-C3 domain core + fault-aware protocol (#10)
    New crate firmware/domain (spool-sentry-domain): allocation-free no_std
    domain logic exercised entirely on the host through injected adapter
    traits (FW-002), plus an ESP32-C3 release link proof.
    - Sampling/filtering with explicit fresh/settling/stale/disconnected/
    saturated/out-of-range states; median-of-window stability detection
    - Gross/net mass with user-entered tare, negative-net fault, and honest
    null uncertainty plus explicit uncertainty_not_characterized fault
    - Two-point tare/reference calibration lifecycle with single-use random
    tokens, expiry, and invalidation
    - Dual-slot bounded storage: FNV-1a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
    [core.rs, faults.rs]
2026-09-10 feat(app): accessible local web companion + data controls (issue #5) (#11)
    Issue #5. Pinned TypeScript/Vite workspace (app/) that builds a small,
    dependency-free static bundle for on-device hosting:
    - protocol v0.1 gate: reject unsupported majors, tolerate additive minors
    - connection/freshness/stale/fault/calibration status with text-first
    (never color-only) state semantics; stale data stays visible, labeled
    - guided tare/reference calibration, spool empty-mass entry, event notes
    - bounded history with retention mirror + text data-table summaries
    - versioned CSV import validated against the frozen firmware CSV header;
    malformed rows reject the whole file before any mutation
    - backup va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
2026-09-12 feat(hardware): carrier PCB + editable force-path mechanics (#12)
    * wip: Analog/Power netclass rules in project file
    * feat(hardware): carrier PCB + editable force-path mechanics for issue #3
    - hardware/spool-sentry.kicad_pcb: 66x75 mm two-layer carrier generated
    via scripts/build_pcb.py (pcbnew API, KiCad 9.0.9 image); placed,
    net-class-bound (Power/Analog in .kicad_pro with netclass_patterns),
    GND-poured both layers, antenna/edge keepouts as priority-1 rule areas,
    DRC-adjudicated SES routing passes (final: 0 hard violations, explicit
    ratsnest residual + named fixes in docs/verification/issue-3-pcb.md)
    - scripts/: board gen + zone/keepout management, DSN/SES loop helpers,
    dete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
    [pass1.dsn, pass2.dsn, pass3.dsn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]
